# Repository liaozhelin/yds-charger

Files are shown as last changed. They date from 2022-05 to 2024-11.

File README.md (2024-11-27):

# 四路桌面智能充电站

> 这是一个实用型智能多路桌面充电器项目
>
> 视频介绍：[【开源】如何自制一个全能桌面充电站？](https://www.bilibili.com/video/BV1X94y1U7av/)
>
> 如果觉得视频还可以的话，留下一键三连哦 ( ˊ•̥▵•)੭₎₎
>
> 本项目欢迎复刻，禁止商用！！
>
> 整体成本（纯硬件）在50元左右，目前没有贵的离谱芯片，选用的芯片基本都是国产使用量较高的
>
> 有任何问题请在`issues`中提交哈，包括软件功能建议，其他平台的消息不一定看得到👀
>
> * 最近在咸鱼上能看到很多本项目的166W充电器的套件以及成品。在此声明这些均非本人上架，本人所有资料无偿开源，未从其中收取任何利益！本项目欢迎大家复刻改进、在合适的价格下出售有限数量的成品/套件（时间精力也是成本）方便新人，但不是商业化批量生产，高价出售并以此赚钱。有大佬在开源代码的基础上改进，并无偿开放了固件，在此表示感谢。请大家共同维护开源环境，国内开源环境已经很难了，尊重技术和开发者，开源才能走的更远！ 
>
> * 由于本人精力有限，未能继续维护该项目固件，在此和大家说一声抱歉~，但是还是有大佬们继续帮忙维护该项目固件，大家可以关注下他们的仓库，谢谢~~
>
>   [Zyilin98仓库]: https://github.com/Zyilin98/yds_charger?tab=readme-ov-file	""Zyilin98仓库""

5E3306F0C8ED8A1241D5FD975B7F77DC

**仓库目录说明**

1. `Hardware`：【上层板/下层板/前面板/后面板 】gerber文件/原理图源文件/原理图PDF文件/坐标文件/BOM文件
2. `Firmware`：【 ESP32C3FN4 的固件以及工具 】固件/驱动/下载烧录软件
3. `Software`： 【 软件工程源码 】esp-idf-4.4 版本开发环境
4. `Structure`： 【 整机结构文件 】包含电路板及外壳装配文件，软件版本Soliworks2022
5. `Documents`： 【 项目所用到的文档手册等 】部分手册，有些手册是厂家不让流传的没有上传

**资料说明 （更新日期22-5-30）**

- 已添加gerber文件，包含上层版，下层板，前面板，后面板，可直接打样（上层板若审核不通过备注断板不补即可）
- 已添加原理图源文件
- 已添加 README 文件 
- 已添加烧录软件,bootloader固件以及app固件
- 已添加结构设计文件夹
- 已添加手册文件夹
- 已添加 esp32c3 usb cdc/jtag驱动文件
- 已添加源码工程文件夹，希望大佬们可以帮忙改进，代码里有什么错误以及疑问都可以提交issue交流，当然能帮我完善功能就更好了😊
- 已提交新版上层板 (Gerber_topBoard-Fix.zip) ，修改掉不好生产的边框处后两层板实在没办法走通，改成四层板了，打样一样免费，就是颜色可能也得绿色了，可以先试试原版两层板，有概率通过，不通过再换成新版上层板。👀
- 已添加上下层板的动态BOM表，说明文件，可以方便焊接选料，若打样嘉立创不通过可以考虑捷配，新用户也可以免费打板审核也比较松。
- 已添加器件采购指南，只做样例，若链接失效自行找类似器件替换。
- 已添加不同丝印版本的文件，在每个板子文件夹中的others文件夹中，每一块板子都提供了3种不同的丝印版本，降低打样时候判定拆单的概率（实在不行就换其他打板公司或者换不同时间打样，基本上只要是机审就可以通过）
- 已经修改20V空载输入发热问题，更换3904的两个上拉电阻即可。

## 一、项目介绍：

### 1.1 硬件选型：

> 本项目的硬件购买都来自于淘宝，虽然有可能有假货，但是我没有翻车，大家可以酌情选择。

- 项目采用乐鑫**ESP32C3FN4**芯片作为控制MCU，具备Wifi和Bluetooth，价格便宜功能强大，可供二次开发增加许多其他功能(内置4M的FLASH)。
- C口功率级采用了智融**SW3526**的功率芯片（目前价格4.5元一片😍），该芯片支持多种快充协议，芯片内部集成功率管，减少PCB面积，最大功率为单通道65W，本项目中设计了两组通道。
- A口功率级采用了英集芯的**IP6525T**，价格低廉（目前价格1元一片😍），最大功率为单通道18W，本项目中设计了两路, 设计在机身后部, 主要是给桌面上的固定设备供电, 比如台灯, 小服务器等, 可通过MOS管远程控制开关
- 交互界面显示屏采用了**0.96**寸OLED屏（尺寸刚好,至于烧屏问题后面会通过屏保解决）。
- 输入部分设计了保护电路，具备防反接（方便车充应用）功能，反接系统不会工作。具备过流保护电路（10A），过流会熔断保险丝。具备防打火缓启动电路，可以防止上电火花。
- 板载四路RGB指示灯以及面板，可以实现当前系统状态的快速指示。
- 加速度传感器为**LIS3DH**，可以实现震动控制或者体感操作等功能。



### 1.2 项目参数

输入电压：10V-32V直流 (推荐使用换下来的笔记本充电器,咸鱼便宜量大,当然更推荐24V5A台达电源,可以最大程度发挥功率)

输入功率：＞80W （满载144W，但是一般不会全部满载）

快充参数如下：

- C口输出协议：PPS/PD3.0/PD2.0/QC4+/QC4/QC3.0/QC2.0/AFC/FCP/SCP/PE2.0/PE1.1/SFCP/BC2.1/苹果/三星
- C口输出电压：0.3-22V
- C口输出电流：0-3.3A
- A口输出协议：DCP/QC2.0/QC3.0/FCP/AFC
- A口输出电压：0.3-12V
- A口输出电流：0-3A

PCB参数：47*80(mm) 厚度1.6mm 四层板

整体尺寸（含外壳）：50X*20X*80(mm)

## 二、制作教程

### 2.1 制作注意事项

> 本产品焊接完成，测试无短路虚焊后，可通过下载口USB连接电脑，烧写程序后即可使用（ESP32C3自带内部USB和JTAG,十分方便）,如果不识别可能需要自行下载C3驱动安装即可

- 装机时请注意功率级部分的散热，推荐在功率级部分背面垫导热片增强散热能力。
- 焊接推荐采用钢网焊接，本项目中器件均为单面布置，可以快速实现低成本回流焊。
- 初次上电时，推荐使用5V电源，测量RY8411输出正常3.3V后才可以升高电压进行后面的测试。
- C1口为板载，C2口通过排针在上层板中引出。

上层板和下层板装配采用常规排针排母，但是排针需要**特殊处理**下，去掉塑料部分直接焊接，不然槽间高度不够：

| 第一步 | 第二步 | 第三步 | 第四步 | 第五步 |
| --- | --- | --- | --- | --- |
|  |  |  |  |  |
| 将排针插进上层板，顶在桌面上，往下按 | 取出后可以得到如上排针，按照这个样式制作三组 | 用水口钳去掉塑料部分，得到针脚 | 将排针插进下层板焊接好的排母中 | 将上层板子和下层板紧贴，排针插进洞中，然后焊接，这个距离刚刚好是两槽间距离 |

上层板的上面焊接完后，可以在上层铝壳对应位置贴上黑胶布绝缘（不贴也可以，实际上还有一定距离，保险起见）

### 2.2 固件烧录教程

> 通过Fireware/tools文件夹中的 flash_download_tool_3.9.2 工具下载
>
> 本项目暂时不提供PCB源文件，源码已经全部开源，有需要二次开发的朋友可以自行修改

	本项目不需要烧录器/下载器，只需要你有一个USB线，但是需要自己焊接一个降压电路将USB口的5V转到3.3V（或者不从排针3.3V处供电，直接通过DC口供电）,**一定不要把5V接到板子上的3.3V处，必烧ESP32**，我是使用了一个洞洞板+AMS1117焊接的简单下载器：

| 烧录器 | 烧录器连接板子 |
| :---: | :---: |
|  |  |

1. 合并固件位置在 `Fireware/bin/target.bin` ，独立固件位置在 `Software/yds_charger` 中，推荐不打算自己后续开发的使用合并bin下载方式。

2.  软件打开后将设备连接到电脑，如图片`图1`设置好下载模式后，点击OK。

3. 【合并bin下载方式】按照下面的图片`图2 `设置好软件，点击下载应该就可以下载固件了，一共需要烧录一个固件即可，地址设置0

4. 【独立bin下载方式】按照下面的图片`图3 `设置好软件，点击下载应该就可以下载固件了,一共需要烧录四个固件，注意地址设置

   > 如果出现连接错误可以将上板后面的拨动开关向左(从前面看，也就是上面板有时间编号的那一边)拨住**不松**，然后再上电，就会进Boot模式）烧录完成，断电后重新上电，应该就可以正常使用了。

	烧录完成后，重新上电复位，就可以使用了。

| 图1 | 图2 | 图3 |
| :---: | :---: | :---: |
|  |  |  |

	OTA采用了 APP+OTA1+OTA2 的乒乓式更新分区（这样就算更新到一半断电断网也不会变砖），首次烧录完后续盖上盖子后，后续就可以使用无线更新了。

## 三、IDF开发

### 3.1 开发环境搭建

	IDF开发环境我是在 Windows 系统中使用 `VScode+idf拓展插件` 在Python虚拟环境中实现开发的，实际上也可以在Linux中直接搭建环境开发，或者使用`WSL+VScode远程插件` 也是可以的，可以根据自己的需要进行选择，详细的搭建步骤可以见[官网搭建流程](https://docs.espressif.com/projects/esp-idf/zh_CN/release-v4.1/get-started/index.html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)：

	下面以我的`VScode+idf拓展插件` 搭建环境为例：

1. 安装Vscode，这个直接下载安装即可，然后在左侧的应用市场中，搜索关键词 Espressif IDF，安装：

   

2. 插件安装完成后，按`F1`,在命令中找到`Configure ESP-IDF extension`选项，点击：

   

3. 选择ADVANCED模式，可以详细配置一些选项：

   

4. 依次设置软件源，IDF版本，IDF路径，IDF工具路径。软件源如果你科学就可以直接选择Github，没有科学可以选择Espressif的国内源，IDF版本这里选择`release/4.4`,其他两个可以根据自己进行设置（路径中不要出现中文或者空格），推荐使用默认路径，然后点击 `Install` 进行安装：

   

5. 等待ESP-IDF下载安装完成，IDF整体体积不小，具体看网速：

   

6. 接下来安装ESP-IDF工具，其中包含虚拟环境以及虚拟环境中用到的一些工具链，选择 `Download ESP-IDF Tools`选项，点击 `Download Tools`：

   

7. 等待工具安装完成：

   

8. 若出现如下页面，则安装完成，如果上述中有步骤报错，一般就是网络问题：

   

### 3.2导入工程开发

	本项目的工程在 `Software/yds_charger` 下，将项目克隆到本地，主要修改项目中的.vscode文件夹，这个文件夹中的文件控制着IDF插件的功能以及Vscode本身的代码高亮提示跳转等。

	先验证安装环境是否可以正常使用，按`F1`,在命令中找到`New Project`,点击：



	根据自己喜好修改工程名，路径，板子，串口（没接上电脑就不用选），最后一个选项可以不管，点击 `Chose Template`：



	下拉框中选择 `ESP-IDF` ,这里可以选择一个最简单的项目测试下，`sample_project`，选择好后点击蓝色按钮生成工程，并信任文件夹中的作者并启用所有功能:



	点击工程下面框中的编译按钮，等待编译完成，若能成功生成bin文件则环境搭建成功（编译如果很慢的话，关闭Windows的病毒防护，可以极大提高编译速度）：





	验证完编译环境后，可以将示例工程中.vscode中文件复制到克隆下的工程中，或者使用 `F1` 中的添加.vscode文件命令也可以，应该包含下面四个文件：



	后面就可以愉快地开发了，烧录下载也一样是用下面的按钮，这里就不赘述了：



**功能开发（更新日期22-5-27）：**

✅ 已经开发完成   🚩正在开发中   ❌还未开发或放弃开发

| 设计功能 | 状态 | 说明 |
| :---: | :--: | :---: |
| 远程网络升级（OTA） |  ✅ | 带固件版本号校验 |
| WIFI配网 |  ✅ | 通过ESPTouch软件配网 |
| 主界面显示 |  ✅ | 待机休眠屏保待完善 |
| 快充协议解析 |  ✅ | 已实现 |
| RGB指示灯 |  ✅ | 已实现，控制逻辑待完善 |
| 各口电压电流监测 |  ✅ | 已实现 |
| 过流反接保护 |  ✅ | 以实现，已校验 |
| 远程控制充电器四口开关 |  🚩 | 硬件已验证，还未写逻辑 |
| 加速度计(重力感应) |  🚩 | 程序已驱动，还未写功能 |
| C口功率限制 |  🚩 | 程序已实现，界面还未增加 |
| OTA自动检测版本升级 |  🚩 | 版本验证已完成，json解析还在修改 |
| 电脑CPU占用，内存占用显示  |  ❌ | 还未开发 |
| 天气显示 |  ❌ | 还未开发 |
| 粉丝数显示 |  ❌ | 还未开发 |
| 重力旋转屏幕 |  ❌ | 还未开发 |
| 蓝牙广播检测手环自动开关机 |  ❌ | 还未开发 |
| | | |
| | | |
| | | |

> 本项目禁止商用，仅供同好们复刻使用，在制作项目时候，请确保硬件无故障再连接设备使用（我已经使用了两个月，目前没有出过问题，手头设备不是很多，所以测试可能不是很完善，不能保证系统不存在隐藏的问题。希望大家能发现问题一起改进），对于造成高价值设备损坏以及其他连带损失的的，本人不承担任何责任哈。
>
> 海拔高度：＜ 2000米
>
> 环境湿度：≤ 75% RH
>
> 工作环境：0℃ - 50摄氏度

大佬们复刻成功的成品 (每一张表格是同一作者的成品)：

`2022-6-13`

|  |  |  |  |
| --- | --- | --- | --- |

`2022-6-14`

|  |  |  |  |
| --- | --- | --- | --- |

`2022-6-16`

|  |  |  |  |
| --- | --- | --- | --- |

`2022-6-18`

|  |  |  |  |
| --- | --- | --- | --- |

......

🙌有啥问题随时提issues，已经有人复刻成功了

......

最后纪念一下开发过程中的炮灰小弟们，第一代和第三代还有打孔歪了的==（总共迭代了5版本，其中有2代搬板拆了）：

|  |  |
| --- | --- |

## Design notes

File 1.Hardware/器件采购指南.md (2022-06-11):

# 四路充电器-采购指南

更新日期：5月30日

> 所有的器件，推荐有闲钱的可以上立创商城之类的购买，保证正品，如果想要折腾的可以在淘宝购买即可（我的器件都是淘宝买的）

以下的指南主要是一些比较难采购到的器件，很常见的电阻电容之类的就不说了：

- 主芯片是 ESP32C3FN4, 要买有内置FLASH版本的

- 外壳：https://item.taobao.com/item.htm?id=596749209315

- 下层板：

| 位号 | 关键字 | 链接 | 图片 |
| :---: | :---: | :---: | :---: |
| L1,L2 | CEP1411NP | https://item.taobao.com/item.htm?id=39992169602  |  |
| L5,L6 | RH屏蔽电感 | https://item.taobao.com/item.htm?id=623801536508 |  |
| C1,C44 | 直插固态电容 | https://item.taobao.com/item.htm?id=660777715260 |  |
| C59,C60,C4,C65,C61 | 高频低阻直插铝电解电容 | https://item.taobao.com/item.htm?id=618159081612 |  |
| C21,C50 | 高频低阻长寿命直插电解电容 | https://item.taobao.com/item.htm?id=617486024887 |  |
| U1,U2 | SW3526 | https://item.taobao.com/item.htm?id=645362899959 |  |
| | | | |

- 上层板：

| 位号 | 关键字 | 链接 | 图片 |
| ---- | --- | --- | --- |
| SW2  | 转换开关 三向开关 | https://item.taobao.com/item.htm?id=614104886426  |  |
| USB1 | TYPE-C 母座 USB 3.1 | https://detail.tmall.com/item.htm?id=668795388622 |  |
| | | | |

- 上下板连接器：使用普通的2.54排针，下层焊接排母，上层排针**去掉塑料**部分，直接焊接

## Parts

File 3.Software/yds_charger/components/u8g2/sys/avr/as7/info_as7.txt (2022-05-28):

001: plain as7
002: create a new gcc c executable project, enter a useful name and solution name
003: select your target device
004: as7 will generate a main.c file. Replace the content of the generated main.c with 
the content of https://github.com/olikraus/u8g2/blob/master/sys/avr/atmega328/main.c
005: open the project Properties (Alt+F7)
006: Add Existing item...
007: Mark and add all files of the u8g2/csrc directory, press "add"
008: Select the project, locate Toolchain tab, select "All Configurations", select AVR/GNU C Compiler/Directories and press the green plus icon
Add ".." as relative include path
009: Select the project, locate Toolchain tab, select "All Configurations", select AVR/GNU C Compiler/Symbols and press the green plus icon
Add the target frequency of your controller (here: "F_CPU=8000000")
010: Press F7 (Build->Build Solution)
011: On my own Windows 10 environment, it was required to install a different usb driver for the AVRISP mkII
012: Open the Device Programming dialog (Tools menu)
013: 
	Select your ISP tool in under "Tool". Select the correct target device and interface. Press "Apply" button.
	Read the device signature from your target controller by pressing the "Read" button.
	Goto "Production file" tab and select the generated .elf file as a "production file"
014: Check "Flash" and press the "Program" button.

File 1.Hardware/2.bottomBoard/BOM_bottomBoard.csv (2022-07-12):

ID | Name | Designator | Footprint
1 | RY8411 | BS | SOT-23-6_L2.9-W1.6-P0.95-LS2.8-BL
2 | 220uF/35V | C1,C4,C44,C61,C65 | CAP-TH_BD8.0-P3.50-D0.6-FD
3 | 105 | C2,C3,C6,C8,C9 | C0603
4 | 107 | C5 | CASE-B_3528
5 | 104 | C7,C14,C16,C17,C18,C54 | C0603
6 | 225 | C10 | C0603
7 | 475 | C11,C12 | C0603
8 | 106 | C13,C15 | C0603
9 | 10p | C19,C20 | C0603
10 | 470uF/16V 8*9 | C21,C50 | CAP-TH_BD8.0-P3.50-D0.6-FD
11 | 0.1u | C22,C29,C32,C35,C38,C43,C46,C49,C51,C55,C56,C57 | C0603
12 | 10u/35V | C23,C33 | C0805
13 | 0.1u/50v | C24,C30,C37,C47,C48 | C0603
14 | 22u/35V | C25,C42 | C0805
15 | 330p | C26,C27,C40,C41 | C0603
16 | 1n | C28,C39,C45,C52 | C0603
17 | 1u | C31,C36 | C0603
18 | 10u/25V | C34,C62 | C0805
19 | NC | C53,C63 | C0603
20 | 10u/35V | C58 | C0603
21 | 100uF/35V 8*9 | C59,C60 | CAP-TH_BD8.0-P3.50-D0.6-FD
22 | 10u | C64 | C0805
23 | BZT52C3V3_C216707 | D2 | SOD-123_L2.7-W1.6-LS3.7-RD
24 | DC-044A-20A | DC2 | DC-IN-TH_DC-044A-20A
25 | Header-4P | H1,H7 | HEADER-4
26 | HDR-F-2.54_1x3 | H2,H3,H4,H5,H6 | HDR-F-2.54_1X3
27 | 22uH | L1,L2 | IND-SMD_3P-L14.5-W14.5
28 | 2nH | L3 | L0603
29 | AN9520-245 | L4 | ANT-SMD_L9.5-W2.1
30 | 22uH | L5,L6 | IND-SMD_L12.0-W12.0_CDRH127NP
31 | 4.7uH | L7 | IND-SMD_L4.0-W4.0_CD43L-10UH
32 | WS2812B-2020 | LED1,LED2 | LED-SMD_4P-L2.0-W2.0-TL_WS2812B-2020
33 | VG-2864KSWEG01 | OLED1 | OLED_0.96-30P-P0.70-12864
34 | TPCA8016-H | Q1 | POWERVDFN-8_L6.2-W5.2-P1.27-LS6.0-BL
35 | SI2309 | Q2,Q3 | TO-236-3_L2.9-W1.3-P1.90-LS2.4-BR
36 | LMBT3904DW1T1G | Q4 | SOT-363_L2.0-W1.3-P0.65-LS2.1-TL
37 | 10K | R1,R4,R6,R21,R24,R29,R30 | R0603
38 | 2R | R2,R13,R15,R16 | R0603
39 | 10mR | R3,R14 | R1206
40 | 33K | R5,R12 | R0603
41 | 4.7K | R7,R8,R11 | R0603
42 | N/A | R9 | R0603
43 | 910K | R10 | R0603
44 | 62K | R17 | R0603
45 | 20K | R18 | R0603
46 | NC | R19 | R0603
47 | 51K | R20 | R0603
48 | 6.2K | R22,R25 | R0603
49 | 1k | R23,R26 | R0603
50 | 1K | R27,R28 | R0603
51 | SW3526 | U1,U2 | QFN-24_L4.0-W4.0-P0.50-TL-EP2.5
52 | IP6525T | U3,U8 | ESOP-8_L4.9-W3.9-P1.27-LS6.0-BL-EP
53 | ESP32C3 | U4 | QFN-32_L5.0-W5.0-P0.50-BL-EP3.7
54 | 1808 Base | U5 | FUSE-SMD_L9.7-W5.0
55 | 1N4148FL | U6 | SOD-123FL_L2.8-W1.7-LS3.6-RD
56 | LIS3DHTR_C15134 | U9 | LGA-16_L3.0-W3.0-P0.50-TL
57 | TYPE-C16PIN | USB1 | USB-C-SMD_TYPE-C16PIN
58 | USB-240-BRW | USB3,USB8 | USB-A-TH_USB-240-BRW
59 | 40MHz | X1 | CRYSTAL-SMD_4P-L3.2-W2.5-BL

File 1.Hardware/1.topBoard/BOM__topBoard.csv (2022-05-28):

ID | Name | Designator | Footprint | Quantity
1 | 104 | C1,C2,C17 | C0603 | 3
2 | HDR-F-2.54_1x3 | H2,H3,H4,H5,H6 | HDR-F-2.54_1X3 | 5
3 | WS2812B-2020 | LED1,LED2 | LED-SMD_4P-L2.0-W2.0-TL_WS2812B-2020 | 2
4 | 10K | R1,R2,R6 | R0603 | 3
5 | TM-2022-3 | SW2 | SW-SMD_TM-2022-3 | 1
6 | TYPEC-302-BRP16SC08 | USB1 | USB-C-SMD_TYPEC-302-BRP16SC08 | 1

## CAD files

3.Software/yds_charger/components/u8g2/sys/arduino/u8g2_full_buffer/SwitchBox/board.dxf
60
40
52
8
24
80
30
32
25
100
190
4
12
6
14

3.Software/yds_charger/components/u8g2/sys/arm/stm32l031x6/clock.dxf
65
32
28
16
Draufsicht
Vorderansicht
von unten
von rechts
von links
14
6
45
60
30
20
8
35
75
55
10
12

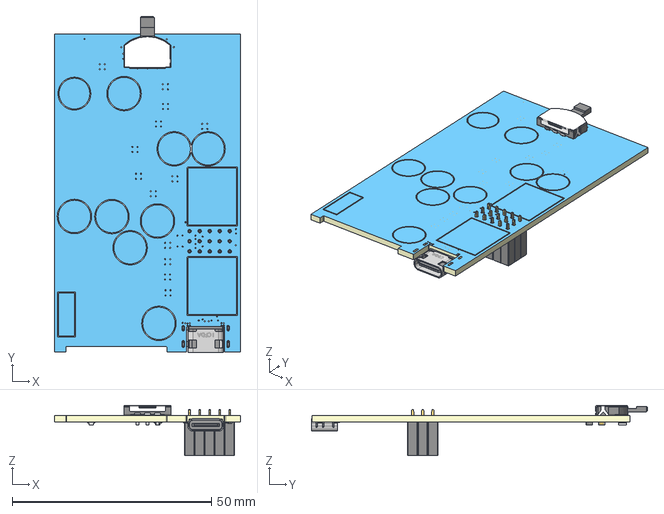
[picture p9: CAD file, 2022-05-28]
4.Structure/bottomBoard/3D_2_PCB_Daughter-Board_2022-04-09_2022-04-09.step
46.7 x 84.2 x 12.6 mm

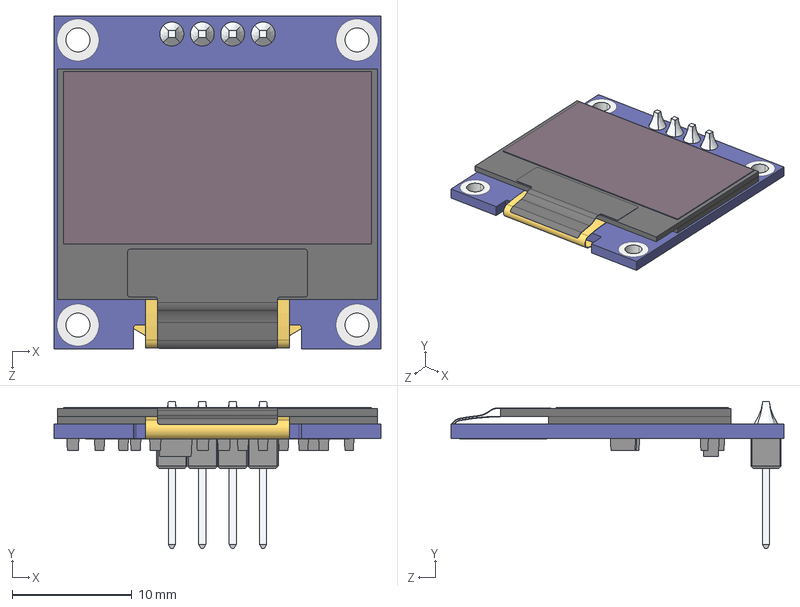
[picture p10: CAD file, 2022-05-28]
4.Structure/otherModule/OLED/OLED TFT 0.96 inch 64x128 monochrome.STEP
27.3 x 12.3 x 27.8 mm

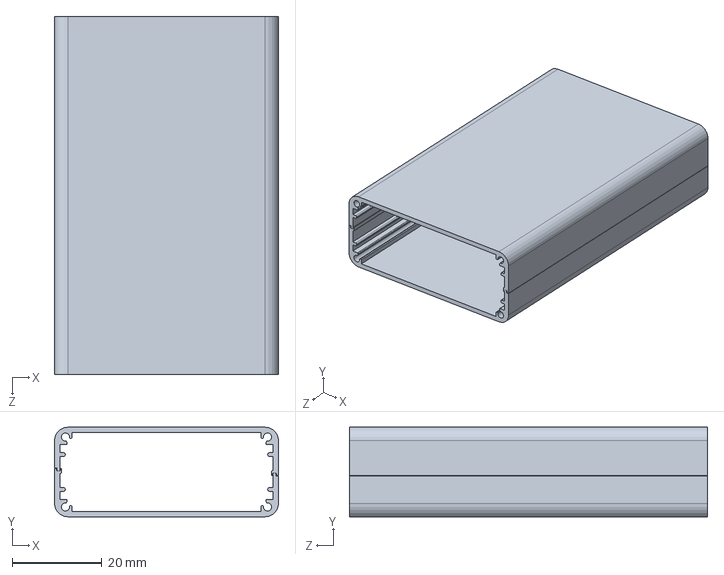
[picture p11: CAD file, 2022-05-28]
4.Structure/铝壳2050.SLDPRT
50.0 x 20.0 x 80.0 mm

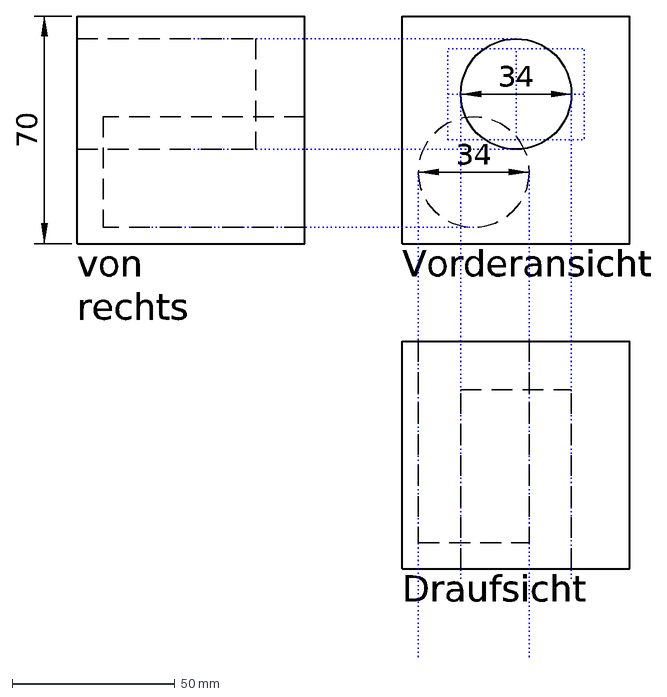
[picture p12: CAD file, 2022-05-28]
3.Software/yds_charger/components/u8g2/sys/arm/stm32l031x6/clock_cube.dxf
Draufsicht
Vorderansicht
von rechts
70
34

3.Software/yds_charger/components/u8g2/sys/arm/stm32l031x6/clock_2.dxf
65
Draufsicht
Vorderansicht
von unten
von rechts
von links
14
30
32
35
75
55
10
12
16
11
22
34
28
29
18
93
19
43
15
68
60
57
150
Holzbohrer: 2.5, 8, 10, 12, 16, 32mm
8
7
6
2.5mm

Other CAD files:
4.Structure/otherModule/OLED/OLED TFT 0.96 inch 64x128 monochrome.SLDPRT
4.Structure/otherModule/OLED/OLED TFT 0.96 inch 64x128 monochrome.x_t

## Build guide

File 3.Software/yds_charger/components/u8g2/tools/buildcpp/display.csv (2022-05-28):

# 1. device name
# 2. pinset
# 3. constructor name w/o prefix
u8x8_d_ssd1306_128x64_noname | 4WSWSPI | SSD1306_128X64_4W_SW_SPI
u8x8_d_ssd1306_128x64_noname | 4WHWSPI | SSD1306_128X64_4W_HW_SPI
u8x8_d_ssd1306_128x64_noname | 3WSWSPI | SSD1306_128X64_3W_SW_SPI
u8x8_d_ssd1306_128x64_noname | SSDSWI2C | SSD1306_128X64_SW_I2C
u8x8_d_ssd1306_128x64_noname | 6800 | SSD1306_128X64_6800
u8x8_d_ssd1306_128x64_noname | 8080 | SSD1306_128X64_8080

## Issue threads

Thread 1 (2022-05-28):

制板的时候的问题

Zyilin98, 2022-05-28:
找jlc制顶板的时候 被嘉立创告知无法制版 需要修改图纸
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
这个是直接告啥嘉立创直接做 还是需要硬件部分迭代

Zyilin98, 2022-05-28:
顺便老哥 你传个LICENSE文件到GitHub上 保证一下开源协议 省的被人直接扒走

liaozhelin, 2022-05-28:
你好，这个直接标注强制生产即可（断板不补就行），后续我会修改一版，去掉这些细连接处，尽可能降低生产的难度

liaozhelin, 2022-05-28:
> 顺便老哥 你传个LICENSE文件到GitHub上 保证一下开源协议 省的被人直接扒走

好的谢谢提醒，我资料还没上传完，等弄好把license也整上

Zyilin98, 2022-05-28:
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
ma'le麻了 给他说了直接做就行 断了就断了 结果还不行 我好佩服嘉立创这么敬业

liaozhelin, 2022-05-28:
> 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
> ma'le麻了 给他说了直接做就行 断了就断了 结果还不行 我好佩服嘉立创这么敬业

好家伙，我之前打样了不下5次都没有问题，现在居然变严格了，那我后面改一版本去掉这些细的边框看看，就是有可能变四层板，有些线走不出来了hh，你可以换个号试试看，只要不触发人工审核一般都可以通过

Zyilin98, 2022-05-28:
我现在下单全都是 人工审核 不管换哪个号 属实是麻中麻

liaozhelin, 2022-05-28:
>

看来审核规则改了hhh，那我后面改个板子，这个是上层板就是一些转接的功能，你可以先做下层板，备料还是需要些时间的hh

Zyilin98, 2022-05-28:
好的 感谢 先把下层做了吧 上层等迭代吧

liaozhelin, 2022-05-29:
已经提交上层迭代版本

Zyilin98, 2022-05-30:
麻了 老哥你能把 pcb文件私法我一份 我改一下么 今天我又被jlc认为是拼单了 让他生产 就叫我补全款 换个号也这样 麻了

liaozhelin, 2022-05-30:
嘉立创打样成功的人不少欸，现在可能打样的人太多了，可以试一下华秋和捷配，这两个也是免费打样，华秋是四层板刚好可以，你邮箱也发我个哈

Zyilin98, 2022-05-30:
> 嘉立创打样成功的人不少欸，现在可能打样的人太多了，可以试一下华秋和捷配，这两个也是免费打样，华秋是四层板刚好可以，你邮箱也发我个哈，实在不行我再改下发你 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

Zyilin98@gmail.com

liaozhelin, 2022-05-30:
资料已发

Zyilin98, 2022-06-08:
老哥，就是关于esp的接口那里 能不能做个直插式的焊盘 这样也方便焊排针？

QGB, 2022-10-30:
0 C:/test/jlc-eda/hqdfm_hqdl_wz.zip       <76.868 MiB> c39a170fac7e5c70a4e15cb5e3b8f759 7de4cede0c139a28a684beb1d50a0c6915c6ac9bbfe5cffb7e195cd4865488d1
 {'C:/test/jlc-eda/hqdfm_hqdl_wz.zip': [<76.868 MiB>, <2022-10-30__13.30.29__.970>, <2022-10-30__13.30.29__.970>, <2022-10-30__13.29.59__.064>, <0o100666>]}

Closed 2022-05-30.

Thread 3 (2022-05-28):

问一下，有可能公开esp固件的代码么

yelvlab, 2022-05-28:
为了学习思路，实话您这个项目看成品做的效果不错，但是开源之名多多少少差点意思，搭配硬创社，没话说，有可能的话留个话，没可能就关了吧

liaozhelin, 2022-05-28:
说了开源那肯定得开，正在修改依赖的子模块，预计晚上可以上线第一个版本。至于硬创社和我这个项目关系不大，因为这里的资料比硬创社更全

liaozhelin, 2022-05-28:
ho

> 为了学习思路，实话您这个项目看成品做的效果不错，但是开源之名多多少少差点意思，搭配硬创社，没话说，有可能的话留个话，没可能就关了吧

说了开源，那肯定要开的，我还希望有大佬能帮我提交PR完善后续固件，审查我的代码呢。已经整理的差不多了，预计晚上可以上传第一个版本，工作区有点乱正在整理中。至于硬创社，并没有资料是在硬创社独有的，只是给没办法访问github的朋友们一个更方便下载资料的地方（最近gitee都知道，提交每次审核那得烦死），最后希望开源后能够有大佬们一起完善这个项目，我主要用业余时间搞的，很多细节可能都不是很到位，只要不被商业化拿来盈利就可以了😼😼

liaozhelin, 2022-05-28:
已提交源码工程

Closed 2022-05-28.

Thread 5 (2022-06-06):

器件选型问题

stig3, 2022-06-06:
1. R5/R12 两个电阻，规格书要求接33K 1%的实现 65W MAX 输出，原理图上是34K，这个有什么考虑吗？34K是非标电阻，也买不到。
2. R17/R18是开关电源的FB，31K也是非标电阻，建议使用62K/20K这样的搭配
3. C42/C25这两个22uF的电容是跨接在USB BUS上的，这两个电容耐压有要求，不能小于20V，建议标注出来，不然会炸的。
4. C62/C34这两个10uF的电容也要16V电压档的
5. C58这个0603的电容也要耐压35V的

liaozhelin, 2022-06-06:
1. R15/R12这两个电阻，可以使用33K的，这个实际上应该不焊接都可以，作用是在没有I2C配置sw3526时候，通过电阻配置功率

liaozhelin, 2022-06-06:
已经更新文件

Closed 2022-06-06.

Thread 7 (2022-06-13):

如果使用jlink cmsis-dap 应该怎么接线 我手里暂时还没有usb公头

Zyilin98, 2022-06-13:
老哥 如果使用jlink cmsis-dap 应该怎么接线 我手里暂时还没有usb公头 再为了这个去买 感觉有点不值

liaozhelin, 2022-06-13:
> 老哥 如果使用jlink cmsis-dap 应该怎么接线 我手里暂时还没有usb公头 再为了这个去买 感觉有点不值

这个硬件上无法使用JLINK下载，JLINK的JTAG占用管脚过多，C3引脚都用完了没有引出，USB公头就几分钱一个，所以选用的片内USB下载，这个USB也内建了JTAG调试器的

Zyilin98, 2022-06-13:
串口下载有办法么 没有的话我还是去拆条usb线吧

liaozhelin, 2022-06-13:
> 串口下载有办法么 没有的话我还是去拆条usb线吧
可以串口下载，但是我没有验证，板子背面预留了串口触点，应该是一样的，就是可能需要手动进入boot模式

Closed 2022-06-13.

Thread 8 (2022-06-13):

固件下载进去没显示，led也没亮

X131402, 2022-06-13:
固件是按图片设置下载的，但是我做了三个都没显示，输出全部都正常，不知道是哪里的问题？🥹

liaozhelin, 2022-06-13:
> 固件是按图片设置下载的，但是我做了三个都没显示，输出全部都正常，不知道是哪里的问题？🥹

你好，我复查后发现是第一次提交的教程，有个bin文件的地址有错误，我现在提交了合并版本的固件，已经在我的电脑上验证了教程，可以通过烧录合并固件，直接烧录一个即可，详细说明可以见更新后的Readme。目前固件功能是第一屏还有设置界面，第二界面的天气显示还在开发中，第三界面预留，第四界面是设置界面，可以通过后面的拨动按键切换。如果制作成功也可以在issue中反馈下，给其他人参考😘

X131402, 2022-06-13:
你好，屏幕有显示了，但是卡在wifi网络初始化就不动了，这个是哪里的问题呀。下载的是整合固件

liaozhelin, 2022-06-13:
> 你好，屏幕有显示了，但是卡在wifi网络初始化就不动了，这个是哪里的问题呀。下载的是整合固件
wifi初始化后是提示OK还是ER?

X131402, 2022-06-13:
就是屏幕显示到最后一条wifi网络初始化... ，就不动了，进不了主页面，然后也没显示OK和ER，就卡在那里

liaozhelin, 2022-06-13:
> 好的，谢谢了

你好，已经提交修复版本的固件，你烧录后看看，应该初次是会提示NO，然后后面开关向右拨动四次进入设置界面，选择 **无线配置-配网** 然后再用手机的esptouch软件给设备配网，配网成功后手机会提示设备也会自动退出配网状态，SSID和密码也会存储在设备中，重新上电后应该就会提示OK了

X131402, 2022-06-13:
已经可以了，联网也正常，谢谢!

X131402, 2022-06-13:
感谢！！

Closed 2022-06-13.

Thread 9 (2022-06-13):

识别到设备但无法烧录

blacksr, 2022-06-13:
dalao你好
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
！
使用外部的电源给的3.3，GND和USB的GND共在一起了，识别出设备后烧录时报了以上的错误，波特率1152000和115200都试了都不行，请问是什么原因可能导致的呢
以下是我遇到的一些问题
1、我将元件焊接完成后DC给了5V测量了RY8411输出是3.6V左右，但DC给24V后RY8411输出就是3.3V了，这部分会影响吗
2、电脑识别时会识别出来然后断开再识别再断开，反复不断，此时3.3V供电电流大约是16mA左右，将拨动开关往左拨进入bootmode后就能正常识别了，此时电流大约是20mA左右，请问这样的现象是正常的吗

blacksr, 2022-06-13:
好的好的谢谢解答！
1、电压正常的话我就放心了
2、如果下载模式指的是拉住拨动开关后上电的话，那么我的操作应该是没有问题的，进入了下载模式后就不会断连了，不进入就会，我还没有尝试烧录完成后还会不会断连【因为烧录不进去:(】芯片我刚刚确认了一下，应该是买错了，没有带尾缀FN4
这个是我买的物料链接，看起来是买错了的
https://item.szlcsc.com/3013220.html

liaozhelin, 2022-06-13:
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

是的，ESP32C3物料购买错误这个是我前期的BOM中的疏忽导致的，lceda最开始导出BOM时候去掉了备注栏，没有注明flash版本，前几天已经修订了BOM中器件型号和更新了说明文件，价格上的话应该贵个2元左右

blacksr, 2022-06-13:
另外我使用了PD测试仪测了一下，虽然没有烧录，USBA口其实已经开始工作了，能够测的出来协议了，不过USBC就还不行:)

liaozhelin, 2022-06-13:
> 另外我使用了PD测试仪测了一下，虽然没有烧录，USBA口其实已经开始工作了，能够测的出来协议了，不过USBC就还不行:)

USBC的sw3526应该是要等esp32烧完程序后，i2c配置使能后才可以工作，应该是没有问题

blacksr, 2022-06-16:
更换了32芯片之后就好了！感谢dalao分享的方案！

blacksr, 2022-06-16:
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

blacksr, 2022-06-16:
外壳打算3d打印一个看一下，满载跑一下老化看看温度，要是温度高搞个铝壳底板打印外壳

liaozhelin, 2022-06-16:
不推荐3D打印，散热挺差的，pla肯定会变形，铝壳也不贵，而且还有前后螺丝

blacksr, 2022-06-16:
不行就底板改用铝板加导热贴，3D打印只是外形而已，或者说先用3D打印机验证模型尺寸后面直接CNC一块板子出来，CNC可以薅公司的用一下，打印机我倒是自己有

liaozhelin, 2022-06-16:
原来是有cnc的dalao，那就更舒服了，可以说上下铣些散热沟槽，高功率下应该会更稳定

blacksr, 2022-06-16:
散热还是挺重要的，毕竟我给笔记本充电的话65W是得吃满的，主要是觉得那个通用外壳有点捞

Closed 2022-06-15.

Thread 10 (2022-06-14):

寄了 电脑认不到板子，串口也不认

Zyilin98, 2022-06-14:
反正是历尽千辛万苦终于做出来一个版本 然后 3.3Vdc-dc电路哪里也正常出了3.3V 但是led没一个亮的 双sw3526也没有输出 倒是A口哪里开始有输出了
接电脑 不管是usb直通 （3.3V已经提供了）还是用ch340通过串口连接 设备基本上就认不到 本来我以为是上层版没做的原因 做了顶层版 按着波动开关还是不认  我已经麻了 实在是不知道哪里的问题导致电脑不认esp32了 显示屏还没焊 怕万一esp32烧了 显示屏一块带走 损失更大

liaozhelin, 2022-06-14:
led在没有烧程序的时候亮是正常的，至于不认芯片，这个电脑是提示无法识别的设备，还是什么提示都没有？

Zyilin98, 2022-06-14:
> led在没有烧程序的时候不亮是正常的，至于不认芯片，这个电脑是提示无法识别的设备，还是什么提示都没有？ 主控芯片是否买的有内置flash版本的c3fn4？

电脑什么提示都没有 设备管理器连弹窗都没有 买的是ESP32-C3FH4

liaozhelin, 2022-06-14:
> > led在没有烧程序的时候不亮是正常的，至于不认芯片，这个电脑是提示无法识别的设备，还是什么提示都没有？ 主控芯片是否买的有内置flash版本的c3fn4？
>
> 电脑什么提示都没有 设备管理器连弹窗都没有 买的是ESP32-C3FH4

方便提交下你的焊接完的板子和连线照片嘛？

Zyilin98, 2022-06-14:
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

Zyilin98, 2022-06-14:
还没来得及洗板子.....

liaozhelin, 2022-06-14:
> 还没来得及洗板子.....

目前我所看到的器件应该都正常，可能还是要重点检查下USB DM DP这两个到芯片的焊接是否虚焊

Zyilin98, 2022-06-15:
去量了 出了一个0.15V 然后Q2 Q3这个Si2309 D极只有0.15V的电压 然后Q4 LMBT3904DW1T1G 除了从E_1 E_2这里有高电压 剩下的位置对地基本上没什么电压

Zyilin98, 2022-06-15:
再去看了一下 要么是esp32挂了 要么就是虚焊 因为3.3的电路都蛮好的  我感觉虚焊可能性不高 因为已经尝试过加焊了 拆下来的时候焊盘也没连锡

liaozhelin, 2022-06-15:
> 再去看了一下 要么是esp32挂了 要么就是虚焊 因为3.3的电路都蛮好的 我感觉虚焊可能性不高 因为已经尝试过加焊了 拆下来的时候焊盘也没连锡

是的，如果手头有空余芯片可以替换下看看

gzzz2008, 2022-07-05:
我也出现这种情况，链接电脑没有任何反应，最后怎么解决的呢？

Zyilin98, 2022-07-05:
> 我也出现这种情况，链接电脑没有任何反应，最后怎么解决的呢？

第一个检查3.3V供电有没有出 有了就检查C15的电压是不是3.3V 如果两个都是 还是不认 检查usb接口焊接 和接口定义是不是接错了
然后检查晶振是不是正常工作 是不是正常起振  如果还是不行 就直接换个esp32吧

gzzz2008, 2022-07-05:
没有示波器怎么检查晶振呢？

Zyilin98, 2022-07-06:
> 没有示波器怎么检查晶振呢？

第一个你的晶振得是无源晶振 第二个晶振有四个触点 看四个触点的定义是不是跟pcb上的一样(就是你有没有焊反了)
第三个就是检查有没有起振 这个是必须要示波器的
第第四 看看c15这个电容有没有对地3.3的电压 有才能算esp32可能正常工作 如果没有就esp32根本没有工作

Closed 2022-06-15.

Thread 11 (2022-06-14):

10pf的0603电容电压应该是多少v呢 我找了许多只有50v的

Tomoneplus, 2022-06-14:

liaozhelin, 2022-06-14:
是两个晶振的匹配电容吗，这个无所谓，买耐压最低的就行，有要求耐压的电容是电源主线上的电容

Tomoneplus, 2022-06-14:
还有0.1uf的也是只有50v

liaozhelin, 2022-06-14:
> 还有0.1uf的也是只有50v

0.1uf的电容一般买25V的就可以

Tomoneplus, 2022-06-14:
0.1uf 25v的可以发个连接吗 我找了好多都是50v的

liaozhelin, 2022-06-14:
> 0.1uf 25v的可以发个连接吗 我找了好多都是50v的

可以买50V的，没有问题

Tomoneplus, 2022-06-14:
找到了 1uf25v 105k

liaozhelin, 2022-06-14:
> 找到了 1uf25v 105k

嗯嗯，除了输入总线上的电容外其他电容无需太过在乎耐压值

Closed 2022-06-14.

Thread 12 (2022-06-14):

大佬你好

Sirius-Cooper, 2022-06-14:
大佬你好，我现在做好了，充电啥的功能也实现了，但是WIFI配网完成以后那个气象站不显示，请问这是正常的嘛，还有我想问一下有OTA升级时选中自动更新会是什么反应

liaozhelin, 2022-06-14:
是的，气象站的API还在开发中，因为目前用的个人天气API无法给多人使用，所以先屏蔽了，正在搞服务转发中。OTA升级中的自动更新还未写功能，后续实现的功能就是每天轮询，查询到新固件版本后自动更新。

Sirius-Cooper, 2022-06-14:
好的，感谢大佬

Closed 2022-06-14.

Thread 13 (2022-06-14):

原理图源文件如何打开

Gonglja, 2022-06-14:
哈喽，大佬好，想换点器件，将65w升级为100w，请问原理图源文件是哪个？那个json文件吗？
如方便，告知下软件

liaozhelin, 2022-06-14:
> 哈喽，大佬好，想换点器件，将65w升级为100w，请问原理图源文件是哪个？那个json文件吗？
>
> 如方便，告知下软件

使用lceda打开，换成100w的话可能得重新方案选型才行，这个体积可能不好塞的下

Gonglja, 2022-06-14:
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

好的，感谢，芯片目前考虑 3519、3518s，顺便换一下彩屏

Gonglja, 2022-06-17:
up您好
看了下里面没有pcb文件，方便发下嘛，需要改下设计
我的邮箱是 glj0艾特outlook.com

liaozhelin, 2022-06-17:
> up您好 看了下里面没有pcb文件，方便发下嘛，需要改下设计 我的邮箱是 glj0艾特outlook.com

PCB文件目前暂时不公开哈，可以根据开放的原理图文件自己画，体积增大两层板可以搞定

Gonglja, 2022-06-17:
好的，那我这边设计一下，感谢

Closed 2022-06-14.

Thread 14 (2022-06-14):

SW3526

Sirius-Cooper, 2022-06-14:
大佬你好，我U1的SW3526输入12V时可以正常工作，但是输入24V时接手机充电，电压就会一直快速的在5V和0V之前跳变，然后手机显示也是一直处于充电和未充电两个状态跳变。U2的SW3526是完全可以拉满正常使用的，我想问一下这大概会是什么问题，是芯片坏掉了吗还是电容耐压值不够，求解

liaozhelin, 2022-06-14:
> 大佬你好，我U1的SW3526输入12V时可以正常工作，但是输入24V时接手机充电，电压就会一直快速的在5V和0V之前跳变，然后手机显示也是一直处于充电和未充电两个状态跳变。U2的SW3526是完全可以拉满正常使用的，我想问一下这大概会是什么问题，是芯片坏掉了吗还是电容耐压值不够，求解

我觉得应该是焊接问题或者采样电阻吧，如果是有一组可以的话应该是有问题的那一组检测到过流触发保护之类的

Sirius-Cooper, 2022-06-14:
好的我试试采样电阻喝重新焊接

Closed 2022-06-15.

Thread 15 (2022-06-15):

question

ChinaCKKK, 2022-06-15:
up主您好
已经着手复刻您的项目了，遇到一点问题：3.3V DCDC稳压电路，RY8411芯片反馈电容是使用多大的呢，您的原理图上标注为NC，但是看您发的b站视频，是焊接上了的，所以特此请教up主，望解答，谢谢

liaozhelin, 2022-06-15:
这个可以焊接一个20p的电容，但是影响不大，所以我在bom中去掉了，环路我用示波器看还是挺稳定的

ChinaCKKK, 2022-06-15:
收到，谢谢up主，回复效率太高了，太感谢了
后续有问题可能还要叨扰您，再次感谢，视频已三连！！！

------------------&nbsp;原始邮件&nbsp;------------------
发件人:                                                                                                                        "liaozhelin/yds-charger"                                                                                    ***@***.***&gt;;
发送时间:&nbsp;2022年6月15日(星期三) 晚上9:51
***@***.***&gt;;
***@***.******@***.***&gt;;
主题:&nbsp;Re: [liaozhelin/yds-charger] question (Issue #15)

这个可以焊接一个20p的电容，但是影响不大，所以我在bom中去掉了，环路我用示波器看还是挺稳定的

—
Reply to this email directly, view it on GitHub, or unsubscribe.
You are receiving this because you authored the thread.Message ID: ***@***.***&gt;

liaozhelin, 2022-06-15:
谢谢，仓库中的信息有邮件提醒所以回复比较及时，后续制作中有啥问题再交流哈👀

ChinaCKKK, 2022-06-16:
up主你好，我今天开始下载固件了，遇到点问题：3.3v供电正常，使用的USB转TTL，把上面的器件全都卸下来了，使用杜邦线直接焊接上去的，连接板子的时候只连接了DP和GND，VCC并未连接（5V会烧esp32），然后板子使用DC供电，但是电脑并未成功识别

------------------&nbsp;原始邮件&nbsp;------------------
发件人:                                                                                                                        "liaozhelin/yds-charger"                                                                                    ***@***.***&gt;;
发送时间:&nbsp;2022年6月15日(星期三) 晚上9:57
***@***.***&gt;;
***@***.******@***.***&gt;;
主题:&nbsp;Re: [liaozhelin/yds-charger] question (Issue #15)

谢谢，仓库中的信息有邮件提醒所以回复比较及时，后续制作中有啥问题再交流哈👀

—
Reply to this email directly, view it on GitHub, or unsubscribe.
You are receiving this because you authored the thread.Message ID: ***@***.***&gt;

liaozhelin, 2022-06-16:
连接板子的时候只连接了DP和GND？是少打了嘛？

ChinaCKKK, 2022-06-16:
我就是只连接了中间两根数据线和GND，然后插上电脑，没有反应，已经重新换了一颗芯片了，还是这样，C15电容只有1.2V电压，3.3V供电正常

------------------&nbsp;原始邮件&nbsp;------------------
发件人:                                                                                                                        "liaozhelin/yds-charger"                                                                                    ***@***.***&gt;;
发送时间:&nbsp;2022年6月16日(星期四) 上午9:32
***@***.***&gt;;
***@***.******@***.***&gt;;
主题:&nbsp;Re: [liaozhelin/yds-charger] question (Issue #15)

连接板子的时候只连接了DP和GND？是少打了嘛？

—
Reply to this email directly, view it on GitHub, or unsubscribe.
You are receiving this because you authored the thread.Message ID: ***@***.***&gt;

liaozhelin, 2022-06-16:
重点检查下晶振得焊接，可以去掉晶振两个匹配电容试试，C15为1.5v说明芯片没有正常启动

ChinaCKKK, 2022-06-16:
我是这样接线的，不知道这样对不对

------------------&nbsp;原始邮件&nbsp;------------------
发件人:                                                                                                                        "liaozhelin/yds-charger"                                                                                    ***@***.***&gt;;
发送时间:&nbsp;2022年6月16日(星期四) 上午9:38
***@***.***&gt;;
***@***.******@***.***&gt;;
主题:&nbsp;Re: [liaozhelin/yds-charger] question (Issue #15)

重点检查下晶振得焊接，可以去掉晶振两个匹配电容试试，C15为1.5v说明芯片没有正常启动

—
Reply to this email directly, view it on GitHub, or unsubscribe.
You are receiving this because you authored the thread.Message ID: ***@***.***&gt;

galamygod, 2022-06-17:
老哥，我把6525换成了6505，现在上电9v有七百毫安，去掉u3有一百多毫安，连接dp和dm电脑一点反应没有

galamygod, 2022-06-17:
我又换了一个6505（u8），现在电压9v，电流为16毫安，但是连接电脑没反应，是我驱动问题吗

galamygod, 2022-06-17:
现在排查出的问题就是只要装上u3就会大电流

liaozhelin, 2022-06-17:
> 现在排查出的问题就是只要装上u3就会大电流

IP6525的和连接电脑关系不大，你最好检查一下IP6525和IP6505是不是可以pintopin替换的，正常待机电流在12V时候应该是在30mA左右，驱动的话我仓库里有，得安装才行

liaozhelin, 2022-06-17:
> 老哥，我把6525换成了6505，现在上电9v有七百毫安，去掉u3有一百多毫安，连接dp和dm电脑一点反应没有

重点检查是否有虚焊，以及晶振电路和电源电路，满足这两个条件应该就可以检测到

liaozhelin, 2022-06-17:
> 我是这样接线的，不知道这样对不对
> […](#)
> ------------------&nbsp;原始邮件&nbsp;------------------ 发件人: "liaozhelin/yds-charger" ***@***.***&gt;; 发送时间:&nbsp;2022年6月16日(星期四) 上午9:38 ***@***.***&gt;; ***@***.******@***.***&gt;; 主题:&nbsp;Re: [liaozhelin/yds-charger] question (Issue #15) 重点检查下晶振得焊接，可以去掉晶振两个匹配电容试试，C15为1.5v说明芯片没有正常启动 — Reply to this email directly, view it on GitHub, or unsubscribe. You are receiving this because you authored the thread.Message ID: ***@***.***&gt;

好像没看到您是怎么接线的，主要应该还是上面所说的那些问题

ChinaCKKK, 2022-06-17:
好的，我再去检查检查。大三考研党，没啥时间专门弄这个，也就是闲余时间弄一下。感谢up主

------------------&nbsp;原始邮件&nbsp;------------------
发件人:                                                                                                                        "liaozhelin/yds-charger"                                                                                    ***@***.***&gt;;
发送时间:&nbsp;2022年6月17日(星期五) 晚上6:46
***@***.***&gt;;
***@***.******@***.***&gt;;
主题:&nbsp;Re: [liaozhelin/yds-charger] question (Issue #15)

我是这样接线的，不知道这样对不对
 …
 ------------------&nbsp;原始邮件&nbsp;------------------ 发件人: "liaozhelin/yds-charger" @.&gt;; 发送时间:&nbsp;2022年6月16日(星期四) 上午9:38 @.&gt;; @.@.&gt;; 主题:&nbsp;Re: [liaozhelin/yds-charger] question (Issue #15) 重点检查下晶振得焊接，可以去掉晶振两个匹配电容试试，C15为1.5v说明芯片没有正常启动 — Reply to this email directly, view it on GitHub, or unsubscribe. You are receiving this because you authored the thread.Message ID: @.***&gt;

好像没看到您是怎么接线的，主要应该还是上面所说的那些问题

—
Reply to this email directly, view it on GitHub, or unsubscribe.
You are receiving this because you authored the thread.Message ID: ***@***.***&gt;

galamygod, 2022-06-18:
> > 老哥，我6525换成6505，现在上电9v有七百毫安，把u3有一百多毫安删除，连接dp和dm电脑一点反应没有
>
> 重点检查是否有虚焊，以及晶振电路和电源电路，满足这两个条件应该就可以检测到

电源电路是没有问题的，3.3已经有了，我是用dc供电，然后USB中间两条接到板子上，驱动我双击以后会闪退，我也不知道安装成功没有

liaozhelin, 2022-06-20:
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

如果双击闪退，可以去官网下载自己平台的对应驱动，以管理员模式运行

Closed 2022-06-17.

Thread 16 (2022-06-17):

更改设计

Gonglja, 2022-06-17:
up您好
看了下里面没有pcb文件，方便发下嘛，需要改下设计
我的邮箱是 glj0艾特outlook.com

_Originally posted by @Gonglja in https://github.com/liaozhelin/yds-charger/issues/13#issuecomment-1158735782_

liaozhelin, 2022-06-17:
已经在其他issue回复

Closed 2022-06-17.

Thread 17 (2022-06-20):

插电脑上一直提示未识别的usb设备

Dustl1ght, 2022-06-20:
UP你好，我焊接完然后插电脑上就一直提示未识别的usb设备，是不是跟晶振有关系，我查资料说要用40MHz的无源晶振，我用的有源晶振。

liaozhelin, 2022-06-20:
> UP你好，我焊接完然后插电脑上就一直提示未识别的usb设备，是不是跟晶振有关系，我查资料说要用40MHz的无源晶振，我用的有源晶振。

呃，我用的是无源的，有源的应该需要修改电路变成单端，可以换成无源的试试

Dustl1ght, 2022-06-20:
好的好的谢谢大佬，我买了无源的，在路上了

Dustl1ght, 2022-06-21:
up您好，我人麻了，第一个问题：这个充电器是不是就算不烧录程序，只要所有元器件正常焊接也是可以输出电压的？
第二个问题：我焊接好了全部的元器件，然后发现背面中间的那个A口不能充电，其他的3个口均能充电，于是我就想用万用表量一下是哪个电压没出来，我把表笔往其中一个6525上一放，紧接着啪的一声，然后就是一个火光，炸了一个SI2309，于是我赶紧断电，换了一个2309，然后发现那个6525也烧了，于是我又换了一个6525，然后再上电，直接烧了保险，保险是125V 3A的，我人麻了我接下来是修一修还是说再重新焊个板子。。。。。。

Dustl1ght, 2022-06-21:
> > up您好，我人麻了，第一个问题：这个充电器是不是就算不烧录程序，只要所有元器件正常焊接也是可以输出电压的？ 第二个问题：我焊接好了全部的元器件，然后发现背面中间的那个A口不能充电，其他的3个口均能充电，于是我就想用万用表量一下是哪个电压没出来，我把表笔往其中一个6525上一放，紧接着啪的一声，然后就是一个火光，炸了一个SI2309，于是我赶紧断电，换了一个2309，然后发现那个6525也烧了，于是我又换了一个6525，然后再上电，直接烧了保险，保险是125V 3A的，我人麻了我接下来是修一修还是说再重新焊个板子。。。。。。
>
> 1.是的 2.直接烧6525的我没见过，感觉你可以检查下输出部分是否短路，还有采样环路电阻是否正常，SI2309是控制6525上电的，如果这个炸了说明6525输入部分有短路，也重点检查下输入部分是否有短路情况 PS：整体电路很简单的，这个问题炸器件大概率是短路，重点检查下各部分的阻值，不要盲目瞎换器件，跟着输入查找应该很快能找到问题

谢谢up！！！等明天新的晶振到了我重新做一个试试，我买了至少5套元器件哈哈哈哈，毕竟第一次焊贴片，尽管有热台，用的还是低温锡，还是出了大问题哈哈哈哈，焊过一次就有经验了，等我成功一个我再回头修一下这个坏的

2905058350, 2022-07-04:
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

可以给个bom购买参考吗我有些找不到

Dustl1ght, 2022-07-05:
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

你具体哪个东西买不到，我都是在立创商城和淘宝上一个一个搜的，你需要结合料号和封装自己筛选

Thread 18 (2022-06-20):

boom配件，与

rambodoctor, 2022-06-20:
大佬，请问active boom 的文件该如何使用，小小白正打算复刻你的作品，板子完成打样，正在为boom 的问题发愁  ，另外怎么知道pcb上放置该哪些电容电阻件嘛。  另外大佬如果需要服务器存放升级文件，或者转发天气什么的 ， 我可以提供一台服务器，也可以帮忙采集天气。

liaozhelin, 2022-06-20:
> 大佬，请问active boom 的文件该如何使用，小小白正打算复刻你的作品，板子完成打样，正在为boom 的问题发愁  ，另外怎么知道pcb上放置该哪些电容电阻件嘛。  另外大佬如果需要服务器存放升级文件，或者转发天气什么的 ， 我可以提供一台服务器，也可以帮忙采集天气。

你好，动态bom直接浏览器打开就可以使用了，至于怎么摆放器件就是根据bom就可以了，看位号。服务器的话我自己有，正在开发中，感谢你的好意了～

Closed 2022-06-21.

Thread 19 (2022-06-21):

老哥求救 上层版的问题

Zyilin98, 2022-06-21:
在我烧了两个ESP32 + 两个SW3526 + N个加速度传感器 等等之后 终于写进去固件并且触发快充了
但是 上层版 这里两个led灯也不亮 拨码开关每次在写固件的时候才有效（也许无效但是确实是写进去了固件）
很多功能还是没用办法用 请问一下老哥 这个拨码开关是如何鉴别能正常用的 我已经换了好几个了 还是不能用

liaozhelin, 2022-06-21:
> 在我烧了两个ESP32 + 两个SW3526 + N个加速度传感器 等等之后 终于写进去固件并且触发快充了 但是 上层版 这里两个led灯也不亮 拨码开关每次在写固件的时候才有效（也许无效但是确实是写进去了固件） 很多功能还是没用办法用 请问一下老哥 这个拨码开关是如何鉴别能正常用的 我已经换了好几个了 还是不能用

呃呃，上层LED不亮下层亮应该就是焊接或者排针问题

Closed 2022-06-21.

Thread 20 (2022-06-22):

配网连接WiFi的问题 一些小问题

Zyilin98, 2022-06-22:
昨天解决完硬件问题之后就开始配网 然后发现一个问题 就是配网之后 显示的ip 既不是我这里的公网ip 也不是内网ip 但是路由器网关哪里也确实是查到了这个设备在线
手动OTA固件就会卡住不动 没有反应。

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

然后 topBoard这个pcb原来是单层板么 单层板就没法嫖嘉立创紫 😂

Zyilin98, 2022-06-22:
去重刷了固件 还是一样的问题 获取的ip不对 手动没法ota(还是说这个功能没做) 我刷的是合并固件

michael6555, 2022-06-22:
请问你的也是不是板子上预留给显示屏的位置不对？

Zyilin98, 2022-06-22:
我这就感觉屏线短了点 把显示屏弯成直角感觉有点费劲 怕把屏搞坏

---原始邮件---
发件人: ***@***.***&gt;
发送时间: 2022年6月22日(周三) 中午12:18
收件人: ***@***.***&gt;;
抄送: ***@***.******@***.***&gt;;
主题: Re: [liaozhelin/yds-charger] 配网连接WiFi的问题 一些小问题 (Issue #20)

请问你的也是不是板子上预留给显示屏的位置不对？

—
Reply to this email directly, view it on GitHub, or unsubscribe.
You are receiving this because you authored the thread.Message ID: ***@***.***&gt;

liaozhelin, 2022-06-22:
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

1.这个IP我是用的乐鑫的方法直接读的，我后面验证下，你这个看起来像获取导公网IP了

Zyilin98, 2022-06-22:
1.这个IP怎么看也不像是公网ip 这个ip查过去是美国AT&T 就很头秃 我感觉是哪里逻辑有问题
2.可能是表达问题吧 是铝外壳的前面板和后面板的pcb 这个好像就后面版是双层板 前面板好像是单层板
3.屏线这个我对的是屏线的两个洞对pcb上的洞 还是感觉屏线短了点 下次我自己焊接的时候看看能不能挪一挪
4.OTA服务器在Github么 也许我还得用网关级代理......   路由器之前为了别的智能设备关了双频合一  一会试试光猫自己的2.4Gwifi 再不行 我也就没办法了 看看新的固件版本会不会好一点
issue就不用开启了 能回复就行 谢谢老哥

对了，老哥有没有交流群之类的 这样就省的好多事开issue了

liaozhelin, 2022-06-22:
> 1.这个IP怎么看也不像是公网ip 这个ip查过去是美国AT&T 就很头秃 我感觉是哪里逻辑有问题 2.可能是表达问题吧 是铝外壳的前面板和后面板的pcb 这个好像就后面版是双层板 前面板好像是单层板 3.屏线这个我对的是屏线的两个洞对pcb上的洞 还是感觉屏线短了点 下次我自己焊接的时候看看能不能挪一挪 4.OTA服务器在Github么 也许我还得用网关级代理...... 路由器之前为了别的智能设备关了双频合一 一会试试光猫自己的2.4Gwifi 再不行 我也就没办法了 看看新的固件版本会不会好一点 issue就不用开启了 能回复就行 谢谢老哥
>
> 对了，老哥有没有交流群之类的 这样就省的好多事开issue了

1.呃，这个IP的问题我也不太清除，我这里看看能不能复现，因为我试了用wifi和手机热点获取到的都是本地ip，这个问题后面研究下

Closed 2022-06-22.

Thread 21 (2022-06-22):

人麻了，连接电脑一点反应没有，esp32有3.3v,但是C15只有2.8V

galamygod, 2022-06-22:

galamygod, 2022-06-22:
而且4个输出口都没有电压

galamygod, 2022-06-23:
> 去检测一下晶振 看看晶振是不是正常起振 或者简单一点 看看晶振方向是不是对了 四个口都没电压很正常 如果晶振和周边电路都正常 建议就换一块esp32

我靠，晶振分方向的吗

Zyilin98, 2022-06-23:
咋不分方向 你以为是对称的么 😂 我当初因为没分就烧了一颗esp 应该让作者下次标一下正确方向 应该正确的方向是 40mhz 这个丝印朝着usb外接针的方向 我买的是这样 具体的还得你自己拿万用表试 四个触点有两个是地线 呈对角线的

---原始邮件---
发件人: ***@***.***&gt;
发送时间: 2022年6月23日(周四) 上午9:12
收件人: ***@***.***&gt;;
抄送: ***@***.******@***.***&gt;;
主题: Re: [liaozhelin/yds-charger] 人麻了，连接电脑一点反应没有，esp32有3.3v,但是C15只有2.8V (Issue #21)

去检测一下晶振 看看晶振是不是正常起振 或者简单一点 看看晶振方向是不是对了 四个口都没电压很正常 如果晶振和周边电路都正常 建议就换一块esp32

我靠，晶振分方向的吗

—
Reply to this email directly, view it on GitHub, or unsubscribe.
You are receiving this because you commented.Message ID: ***@***.***&gt;

galamygod, 2022-06-23:
> 咋不分方向 你以为是对称的么 😂 我当初因为没分就烧了一颗esp 应该让作者下次标一下正确方向 应该正确的方向是 40mhz 这个丝印朝着usb外接针的方向 我买的是这样 具体的还得你自己拿万用表试 四个触点有两个是地线 呈对角线的
> […](#)
> ---原始邮件--- 发件人: ***@***.***&gt; 发送时间: 2022年6月23日(周四) 上午9:12 收件人: ***@***.***&gt;; 抄送: ***@***.******@***.***&gt;; 主题: Re: [liaozhelin/yds-charger] 人麻了，连接电脑一点反应没有，esp32有3.3v,但是C15只有2.8V (Issue #21) 去检测一下晶振 看看晶振是不是正常起振 或者简单一点 看看晶振方向是不是对了 四个口都没电压很正常 如果晶振和周边电路都正常 建议就换一块esp32 我靠，晶振分方向的吗 — Reply to this email directly, view it on GitHub, or unsubscribe. You are receiving this because you commented.Message ID: ***@***.***&gt;

现在Q2输出12v（也就是u3有电压，usb3能正常输出），Q3没有电压（相对应的u8没有电压，USB8不能正常输出）

Zyilin98, 2022-06-24:
因为我这边这个双A口电路的大概原理也没看明白 至少我实验的情况是 esp32没正常工作之前 两个A口是没输出的
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
研究了一下电路图和原理图 LMBT3904的中间两个脚通过1K电阻之后 直接连到了esp的这两个U0TXD 和U0RXD上 虽然我确实是不知道为什么要接这.....😅 具体还得问作者

Zyilin98, 2022-06-24:
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

因为我这边这个双A口电路的大概原理也没看明白 至少我实验的情况是 esp32没正常工作之前 两个A口是没输出的
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
研究了一下电路图和原理图 LMBT3904的中间两个脚通过1K电阻之后 直接连到了esp的这两个U0TXD 和U0RXD上 虽然我确实是不知道为什么要接这.....😅 具体还得问作者

liaozhelin, 2022-06-25:
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

是的，这个电路是IO高电平就控制通断，因为C3端口紧张（都用光了）所以复用了串口作为IO，当需要作为下载的时候也不影响，主要是想实现全部端口的控制，前面两个C口也可以通过软件控制通断，后面的A口如果是接一些台灯之类的设备可以实现自动开关灯，主要是这么想的，具体的web界面最近在写了hhhh

liaozhelin, 2022-06-25:
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

一个USBA有电压一个没有的话，建议查看 LMBT3904是不是买错了

Zyilin98, 2022-06-25:
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

我之前也是一个有一个没有 换了板子 换了一颗也就好了 这个件还好我买的多.......... 现在也是A口输出有点问题 打算等有空换换ip6525试试
对了 作者有没有计划 接口握手不通的快充 led显示不同的颜色 的计划 没输出的时候是绿色呼吸/蓝色呼吸 正常5V的时候是绿色呼吸 握手pd协议高电压的时候（例如12V及以上的时候）是红灯呼吸。

liaozhelin, 2022-06-25:
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

有的，您和我想的一样，这个也是我设计四个RGB灯的初衷，四个RGB分别对应快充的四种状态，这个功能加上去很快，应该会在下一版和WEB控制界面一起推出，最近考试事情比较多，要不然之前那一版本就加上了hhh✌

galamygod, 2022-06-30:
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

昨天搞好两块板子（3.3v有，插电脑提示有连接，但是公司电脑装驱动失败），稳压电源上电都没有问题，就拿回宿舍烧录，用的坠机堡垒电源19V-6.5A，结果插上电过一会3904燃起来了，没敢试第二块

galamygod, 2022-06-30:
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

昨天搞好两块板子（3.3v有，插电脑提示有连接，但是公司电脑装驱动失败），稳压电源上电都没有问题，就拿回宿舍烧录，用的坠机堡垒电源19V-6.5A，结果插上电过一会3904燃起来了，没敢试第二块

Zyilin98, 2022-06-30:
一般系统够新驱动就不用装

3904要是老烧就别焊了 si2309直接把锡连上&nbsp;
这边的电路是一个三极管一个mos管拿来通过单片机控制ip6525开关的

---原始邮件---
发件人: ***@***.***&gt;
发送时间: 2022年6月30日(周四) 上午10:47
收件人: ***@***.***&gt;;
抄送: ***@***.******@***.***&gt;;
主题: Re: [liaozhelin/yds-charger] 人麻了，连接电脑一点反应没有，esp32有3.3v,但是C15只有2.8V (Issue #21)

咋不分方向 你以为是对称的么 😂 我当初因为没分就烧了一颗esp 应该让作者下次标一下正确方向 应该正确的方向是 40mhz 这个丝印朝着usb外接针的方向 我买的是这样 具体的还得你自己拿万用表试 四个触点有两个是地线 呈对角线的
 …
 ---原始邮件--- 发件人: @.&gt; 发送时间: 2022年6月23日(周四) 上午9:12 收件人: _@**._&gt;; 抄送: ***@***.***@._&gt;; 主题: Re: [liaozhelin/yds-charger] 人麻了，连接电脑一点反应没有，esp32有3.3v,但是C15只有2.8V (Issue #21) 去检测一下晶振 看看晶振是不是正常起振 或者简单一点 看看晶振方向是不是对了 四个口都没电压很正常 如果晶振和周边电路都正常 建议就换一块esp32 我靠，晶振分方向的吗 — Reply to this email directly, view it on GitHub, or unsubscribe. You are receiving this because you commented.Message ID: _@_.*&gt;

现在Q2输出12v（也就是u3有电压，usb3能正常输出），Q3没有电压（相对应的u8没有电压，USB8不能正常输出）

一个USBA有电压一个没有的话，建议查看 LMBT3904是不是买错了（看看是否买到了3946）

昨天搞好两块板子（3.3v有，插电脑提示有连接，但是公司电脑装驱动失败），稳压电源上电都没有问题，就拿回宿舍烧录，用的坠机堡垒电源19V-6.5A，结果插上电过一会3904燃起来了，没敢试第二块

—
Reply to this email directly, view it on GitHub, or unsubscribe.
You are receiving this because you commented.Message ID: ***@***.***&gt;

Closed 2022-06-25.

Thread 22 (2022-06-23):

关于bom

gxq-is-a-lovely-girl, 2022-06-23:
在底板的bom中C1,C4,C44,C61,C65为一类，在元器件采购指南中C１,C44归为直插固态电容,而C65,C61,C4与C59,C60归为高频低阻直插铝电解电容,我应该按哪个?还有貌似C1,C44(220uf/35V)的尺寸大小bom中没有写是几成几,小白提问勿喷.

Zyilin98, 2022-06-25:
这个东西 我怎么说 具体还得等作者回答 我自己的意见是 SW3526 和ip6525的示例电路中没标注非得是固态电容还是铝电解电容
我自己正好有点余料 刚开始做的是固态和电解混用 后来就是全换固态电容了 看那些做成的大佬 也是电解的多
至于220uf的这个尺寸 我买的是8*11.5MM固态电容 之前库存的是8*12MM的电解电容

Zyilin98, 2022-06-25:
> 这个选料具体还得等作者回答
我自己的意见是 SW3526 和ip6525的示例电路中没标注非得是固态电容还是铝电解电容 我自己正好有点余料 刚开始做的是固态和电解混用 后来就是全换固态电容了 看那些做成的大佬 也是电解的多 至于220uf的这个尺寸 我买的是8_11.5MM固态电容 之前库存的是8_12MM的电解电容

liaozhelin, 2022-06-25:
> 在底板的bom中C1,C4,C44,C61,C65为一类，在元器件采购指南中C１,C44归为直插固态电容,而C65,C61,C4与C59,C60归为高频低阻直插铝电解电容,我应该按哪个?还有貌似C1,C44(220uf/35V)的尺寸大小bom中没有写是几成几,小白提问勿喷.

我自己的话就只有C口输出的两个电容用了固态电容，其他都是普通铝电解电容，具体物料购买地址我记得我有附在采购指南中，您可以去看看

Closed 2022-06-25.

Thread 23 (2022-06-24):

大佬，求指教，RY8411出来电压一直在3.7以上

xiyuxixi, 2022-06-24:
仅焊接原理图中的 输入模块和 3.3V降压模块。 5V输入测试RY8411输出3.7V多。12V的时候在3.5V多。20V输入又上升到3.8V输出。换了好几个RY8411都一样

ktx888, 2022-06-25:
看你这描述不知道是怎么回事，不过我的可以稳定在3.3v

Zyilin98, 2022-06-25:
建议拍个图片出来看看

liaozhelin, 2022-06-25:
是的，这个电路很多人焊接后都没有问题，建议还是检查下器件是不是焊接有误

Closed 2022-06-25.

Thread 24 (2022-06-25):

电感L1发热

gzzz2008, 2022-06-25:
电压不正常，而且电感L1 上电一会就发热了。

gzzz2008, 2022-06-25:
还有能发一份能有电路连接的动态BOM图吗？这样好排查原因。

gzzz2008, 2022-06-25:
还有为什么没有接地呢？

liaozhelin, 2022-06-25:
> 还有能发一份能有电路连接的动态BOM图吗？这样好排查原因。

嘉立创的动态bom插件貌似有bug，我导出是空文件，所以之前用的是脚本导出，您邮箱发我个我给你发下源文件，您那里导出试试

liaozhelin, 2022-06-25:
> 还有为什么没有接地呢？

CDEP电感第三个脚是固定而不是屏蔽，因此不用接低，电感发烫说明输出环路有问题，重点检查下芯片sw引脚和反馈引脚

gzzz2008, 2022-06-25:
> > 还有能发一份能有电路连接的动态BOM图吗？这样好排查原因。
>
> 嘉立创的动态bom插件貌似有bug，我导出是空文件，所以之前用的是脚本导出，您邮箱发我个我给你发下源文件，您那里导出试试

59029226@qq.com

Closed 2022-06-25.

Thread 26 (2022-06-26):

显示屏接线相关优化

Zyilin98, 2022-06-26:
现在的pcb和显示屏之间是靠焊接 连接 而且现在屏线有长有短 经常有屏线够不到或者弯不过来的情况
就能不能改一下显示屏的接线方式
适配这种接线方式
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
我知道这种母座有点难焊
但是最起码可以减小焊接屏幕的损耗 将来屏幕坏了也方便更换

ktx888, 2022-06-26:
1、借楼吐槽一下，我之前就买的这家的30pin的那款显示屏，边框大了一圈，根本装不进去，后来换了一家。
2、我觉得楼主提的也有道理。不过这个显示屏应该也不至于用着用着就坏了吧（我猜的）。
3、up主好像还没有发布新的固件，我自己改了代码，我的支持1分钟无操作自动息屏，也能保护屏幕。我还加了天气预报功能。如果有需要可以找我要，哈哈😃

Zyilin98, 2022-06-26:
> 1、借楼吐槽一下，我之前就买的这家的30pin的那款显示屏，边框大了一圈，根本装不进去，后来换了一家。 2、我觉得楼主提的也有道理。不过这个显示屏应该也不至于用着用着就坏了吧（我猜的）。 3、up主好像还没有发布新的固件，我自己改了代码，我的支持1分钟无操作自动息屏，也能保护屏幕。我还加了天气预报功能。如果有需要可以找我要，哈哈😃

卧槽 我买的就是这家 卧槽了 能给一下你那个新一家的屏幕链接么

ktx888, 2022-06-26:
【淘宝】https://m.tb.cn/h.fwWEmZ6?tk=Bq9x2or860c「0.96寸OLED显示屏 窄边框128*64点阵SSD1315驱动30PIN兼容SSD1306」
点击链接直接打开

Zyilin98, 2022-06-26:
> 【淘宝】[https://m.tb.cn/h.fwWEmZ6?tk=Bq9x2or860c「0.96寸OLED显示屏](https://m.tb.cn/h.fwWEmZ6?tk=Bq9x2or860c%E3%80%8C0.96%E5%AF%B8OLED%E6%98%BE%E7%A4%BA%E5%B1%8F) 窄边框128*64点阵SSD1315驱动30PIN兼容SSD1306」 点击链接直接打开

感谢 这个屏线应该不会很短吧

ktx888, 2022-06-26:
>

不短，正好

ktx888, 2022-06-26:
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

Zyilin98, 2022-06-26:
> 1、借楼吐槽一下，我之前就买的这家的30pin的那款显示屏，边框大了一圈，根本装不进去，后来换了一家。 2、我觉得楼主提的也有道理。不过这个显示屏应该也不至于用着用着就坏了吧（我猜的）。 3、up主好像还没有发布新的固件，我自己改了代码，我的支持1分钟无操作自动息屏，也能保护屏幕。我还加了天气预报功能。如果有需要可以找我要，哈哈😃

对了老哥 我顺带要一份固件吧 试试这个气象站 顺带也看一下我这是不是配网还有问题

ktx888, 2022-06-26:
> > 1、借楼吐槽一下，我之前就买的这家的30pin的那款显示屏，边框大了一圈，根本装不进去，后来换了一家。 2、我觉得楼主提的也有道理。不过这个显示屏应该也不至于用着用着就坏了吧（我猜的）。 3、up主好像还没有发布新的固件，我自己改了代码，我的支持1分钟无操作自动息屏，也能保护屏幕。我还加了天气预报功能。如果有需要可以找我要，哈哈😃
>
> 对了老哥 我顺带要一份固件吧 试试这个气象站 顺带也看一下我这是不是配网还有问题

你加我qq吧，烧程序可能有一些bug，好交流（1760489926）

Runeluna, 2022-06-29:
> 【淘宝】[https://m.tb.cn/h.fwWEmZ6?tk=Bq9x2or860c「0.96寸OLED显示屏](https://m.tb.cn/h.fwWEmZ6?tk=Bq9x2or860c%E3%80%8C0.96%E5%AF%B8OLED%E6%98%BE%E7%A4%BA%E5%B1%8F) 窄边框128*64点阵SSD1315驱动30PIN兼容SSD1306」 点击链接直接打开

谢谢老哥，我搞的另一家也是大了一圈

liaozhelin, 2022-06-29:
这个提议不错，有想自行修改的可以私发我下邮箱，我私发源文件。之前设计的时候我主要是用手头现有的屏幕，所以没有考虑这种接口的形式，果然做的人多考虑的事情就更加周全了👍

Zyilin98, 2022-06-29:
> 这个提议不错，有想自行修改的可以私发我下邮箱，我私发源文件。之前设计的时候我主要是用手头现有的屏幕，所以没有考虑这种接口的形式，果然做的人多考虑的事情就更加周全了👍

我去试试看看能不能换种接口 但是主要是怕出现那种显示屏装不上的问题 我看看咋优化这个pcb板子的开口吧 我看周边应该没电路可能就是led那边的线可能要稍微挪挪 多切一点影响应该不大 我先试试

blacksr, 2022-07-23:
！！我也买了这家！然后发现大了一圈，但是一直没管这个问题，将就用了，这就去换！

blacksr, 2022-07-23:
！！我也买了这家！然后发现大了一圈，但是一直没管这个问题，将就用了，这就去换！

Closed 2022-06-29.

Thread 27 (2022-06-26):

串口

chjdbh, 2022-06-26:
上电会出现串口一秒后消失再过一秒又会出现一直重复这样

ktx888, 2022-06-26:
>

拨盘往左拨之后再上电

chjdbh, 2022-06-27:
还是不行

ktx888, 2022-06-27:
按道理来说不应该，我之前也和你一样一直跳，但是我把排针中间那排最下面的引脚对地短接后（也就相当于拨盘向左拨），再上电就不跳了

Dustl1ght, 2022-06-27:
> 上电会出现串口一秒后消失再过一秒又会出现一直重复这样

我之前也是这样，我换了个无源晶振就好了，之前用的有源晶振，不知道你是不是和我一样的问题

Zyilin98, 2022-06-27:
我之前也有这个问题 加焊了一下usb线和接头 顺带对调了中间的数据线 也好了 不知道是不是这样的问题
也许你得检查一下esp32的3.3V供电

gzzz2008, 2022-07-05:
上电后，串口不显示，一点反应都没有，是怎么回事呢？是我操作顺序有问题？

Closed 2022-06-29.

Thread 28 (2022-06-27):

芯片配网

Dustl1ght, 2022-06-27:
up大大你好，现在我遇到个问题是无法配网，2.4g频段也不行，我用的路由器是wifi6的，我看网上说esp32不支持最新的wifi协议，然后就是配网失败之后就不能再重新配网了，需要重新刷固件才可以

ktx888, 2022-06-27:
兄弟我这有我修改过的固件，在up没更新前可以过渡，如果需要加我QQ发给你1760489926

Dustl1ght, 2022-06-27:
> 兄弟我这有我修改过的固件，在up没更新前可以过渡，如果需要加我QQ发给你1760489926

多谢

Zyilin98, 2022-06-27:
wifi6的路由器关掉多频合一 双频优选 等等 暴露出2.4GWiFi试试

Dustl1ght, 2022-06-27:
> wifi6的路由器关掉多频合一 双频优选 等等 暴露出2.4GWiFi试试

好的好的，我试试

Closed 2022-06-28.

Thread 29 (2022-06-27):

上电后有声音

gzzz2008, 2022-06-27:
插上电源后，总是有吱吱的声音，这是正常吗？不知道什么发的声音，电压总是3.2V，没有3.3V ，烧录不上程序，插电脑没有反应。

Zyilin98, 2022-06-28:
emmm 感觉是哪里短路了 排查一下ip6525T LMBT3904 sw3526本体 type-c接口有没有连锡或者短路
3.3出3.2  3.4都很正常 不是非得要3.3 不过差太多了之后 还是得检测一下哪里有没有焊接问题

Sirius-Cooper, 2022-06-29:
RY8411发热嘛，要不看一下芯片供电正不正常，声音可能是某个电感啸叫（？），几个大电感除了电源芯片就是RY8411那个电感了，看下是不是那里的问题

liaozhelin, 2022-06-29:
主要还是查看下是否存在短路情况，正常空载情况下应该是没有声音的才对，插电脑烧录没有反应可以查看下其他的issues

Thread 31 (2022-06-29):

[硬件] BOM的型号和实际好像有出入

Runeluna, 2022-06-29:
买元件的过程中发现BOM的型号和实际好像有出入，比如C4在bom标注的是220uF，看购买说明上好像是100uF，这个有影响吗，以哪个为准？
还有我看到有一个保险丝座，请问下保险丝选哪种规格，多少V和A的，谢谢

Dustl1ght, 2022-06-29:
> 买元件的过程中发现BOM的型号和实际好像有出入，比如C4在bom标注的是220uF，看购买说明上好像是100uF，这个有影响吗，以哪个为准？ 还有我看到有一个保险丝座，请问下保险丝选哪种规格，多少V和A的，谢谢

我全部按照bom买的，目前没有出现问题，保险丝座嘉立创搜索0154007.DR，总之保险丝座就长这样。保险的规格我一开始用的125V 3A 上电就烧，我后来直接上了125V 10A。这个0154007.DR是7A的，我觉得应该也没问题。

liaozhelin, 2022-06-29:
是的，大部分应该是对的上的，其实也没有多少料，主要是用LCEDA直接生成，应该按照料号都可以找到

Closed 2022-06-29.

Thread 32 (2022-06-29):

LMBT3904双三极管发热严重

Sirius-Cooper, 2022-06-29:
大佬你好，我想问一下LMBT3904双三极管上电之后发热严重是正常现象吗，上电之后空载发热严重，烫手的那种，但是系统可以正常使用

ktx888, 2022-06-29:
我也会，我现在已经把3904拆了

liaozhelin, 2022-06-29:
可以修改3904的上拉电阻到10K就可以了

galamygod, 2022-06-29:
>

我的3904已经烧冒烟了

ktx888, 2022-06-30:
> 我的3904已经烧冒烟了

我3904着过火你敢信，明火

galamygod, 2022-07-02:
> > 我的3904已经烧冒烟了
>
> 我3904着过火你敢信，明火

我的就是插笔记本电源，然后两秒钟的火，还带声音的，然后就是冒烟

XiDD93, 2022-07-04:
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
我也是接笔记本电源烧了，在我手中直接炸开了，但是充电功能好像不受影响，你找到问题原因了吗？

galamygod, 2022-07-06:
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

还没呢，我连程序都还没烧录成功，一直弹USB有问题

e1585742133, 2022-07-09:
检查  一下SI2309  是不是卖家发错货了     我遇见过一样的问题    重新换了SI2309  就好了

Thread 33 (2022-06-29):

分享固件

ktx888, 2022-06-29:
https://wwd.lanzout.com/it6bO07449je
这是我在作者基础之上修改的程序，有需要的可以下载
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

https://user-images.githubusercontent.com/78667688/176445395-e5bfbad2-1bec-4cf9-8f73-0b44ffdd2aef.MOV

liaozhelin, 2022-06-29:
厉害了！天气预报这个功能很实用，还带有上位机，完成度很高了👍最近鸽得有点久，大家可以根据自己的需要修改适合自己的固件，也可以试一下这些大神们的固件，丰富各种玩法，这个issue就不close了，让更多人可以看到✔

mornlena, 2022-07-01:
刷了，很赞~

ktx888, 2022-07-02:
> 刷了，很赞~

哈哈😃

e1585742133, 2022-07-08:
我刷了  黑屏 指示灯也不亮

xiaoqingnian20, 2022-07-09:
刷了，卡wifi初始化

ktx888, 2022-07-09:
开机不停按确认键能进配网

X131402, 2022-07-09:
charger这个软件连接不上，我用udp测试工具是可以通讯的，也有返回功率和电压信息。这是怎么回事

X131402, 2022-07-09:
是1.1那个版本连不上，然后led不亮设置不了

ktx888, 2022-07-09:
试一下charger1.2

X131402, 2022-07-09:
可以连上了，是防火墙那边的问题，但是led不亮了设置了也没反应

ktx888, 2022-07-09:
加QQ吧，这地方回答好麻烦  1760489926

e1585742133, 2022-07-11:
感谢大佬的默默付出

blacksr, 2022-08-11:
感谢dalao的分享！固件刷上了孩子很爱吃

Inevitableofcold, 2022-09-06:
问下3904的两个上拉电阻修改成什么电阻了，哪里可以查看，谢谢O(∩_∩)O

blacksr, 2022-09-06:
> 问下3904的两个上拉电阻修改成什么电阻了，哪里可以查看，谢谢O(∩_∩)O

修改成10K了，BOM表中已经更新过来了，按照最新的BOM表贴就可以了

Inevitableofcold, 2022-09-06:
> > 问下3904的两个上拉电阻修改成什么电阻了，哪里可以查看，谢谢O(∩_∩)O
>
> 修改成10K了，BOM表中已经更新过来了，按照最新的BOM表贴就可以了

问下有两个10uf/35V的C0805贴片电阻买的是25V耐压值的，贴上会不会不能用，谢谢回答

blacksr, 2022-09-06:
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

如果是bom标了耐压值要求的最好上对应的，高了可以的 低了估计会烧板，这里面电路我也不太懂

blacksr, 2022-09-06:
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

看了一下原理图，那颗电容是输入电容，看你输入是多少，耐压值应该不能小于你的输入电压

linkinparkone, 2022-09-16:
> 刷了，卡wifi初始化

请问卡wifi初始化解决了吗？我也遇到了这个问题

Inevitableofcold, 2022-10-09:
问下如果有成品出的话联系我V 13950722089

Inevitableofcold, 2022-10-15:
急收5.5x2.1 至少140W笔记本电源 可以正常给充电站使用的 v 13950722089 可以走咸鱼

djc80s, 2023-03-18:
> https://wwd.lanzout.com/b011rygfa 密码:58r5 这是我在作者基础之上修改的程序，有需要的可以下载 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
看了你仓库开了没放代码，方便分享学习下么。最近正在学习ESP32，按照UP主的配置好后，发现无法编译"'SPI3_HOST' undeclared (first use in this function);"。看到你这有分享，我这就凑上来了。

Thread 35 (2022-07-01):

卡Wi-Fi网络初始化问题

XPY2020, 2022-07-01:
上传程序成功后上电卡在Wi-Fi网络初始化是什么问题
![Uploading 05D3F825-4651-4931-A5AD-9A55078E8ACB.jpeg…]()

XPY2020, 2022-07-01:
![Uploading 23652DD8-1EB5-464C-BA7A-BB810C272022.jpeg…]()

XPY2020, 2022-07-01:
所以up的合并固件上次已经解决了

Closed 2022-07-09.

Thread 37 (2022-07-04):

烧LMBT3904DW1T1G

XiDD93, 2022-07-04:
之前接12v电源没问题，测试完了上19v电源直接LMBT3904DW1T1G着火烧了，换了新的以后接12v电源也一样烧，找了一圈发现SI2309被卖家发错货发成SI2301了，烧LMBT3904DW1T1G会是SI2301的问题吗？

Zyilin98, 2022-07-05:
会

liaozhelin, 2022-07-09:
我的锅，这里上拉电阻应该要改成10K，不过你这着火应该是买错器件了，用1K也就是发热量大

e1585742133, 2022-07-09:
建议拆掉就行了

Closed 2022-07-09.

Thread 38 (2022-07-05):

两个C口均只能输出最高12V

Dustl1ght, 2022-07-05:
我插入我的笔记本电脑只能只能输出12V，无法输出20V，而且需要上电几次才能稳定12V，重新拔插C口数据线有概率会重启设备，我之前已经成功组装了两个了，装第三个的时候出现这个问题了 [https://www.bilibili.com/video/BV1t34y1p72V?share_source=copy_web](url)
@liaozhelin

stig3, 2022-07-05:
你看一下你的输入电源是多少伏的，这个是BUCK型的电源。
另外，看你的描述，感觉是协议没有识别，检查一下焊接呢？

Dustl1ght, 2022-07-05:
> 你看一下你的输入电源是多少伏的，这个是BUCK型的电源。 另外，看你的描述，感觉是协议没有识别，检查一下焊接呢？

 谢谢，电源是24V 6A的，我之前已经焊过两个板子了，都用的挺好，这是第三个，然后就出问题了，而且两个C口都是同样的问题，两个C口的电路都是分开的，按说也不至于两个都这样，会不会是我拿错电容或电阻了

liaozhelin, 2022-07-09:
重点检查焊接以及器件焊接问题

Closed 2022-07-09.

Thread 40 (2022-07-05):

SW3526发热

gzzz2008, 2022-07-05:
SW3526总是发热是怎么回事呢？哪里能短路导致呢？

gzzz2008, 2022-07-05:
好像是IP6525T发热！！我用的是IP6505，这个有影响吗？

gzzz2008, 2022-07-05:
换了IP6525T正常了，但是怎么插电脑没有反应呢？？需要按上上层板子才能插电脑有反应吗？

Zyilin98, 2022-07-05:
不接上层板子 esp32应该是不进bootload模式 电脑应该不认

galamygod, 2022-07-06:
> 好像是IP6525T发热！！我用的是IP6505，这个有影响吗？

不能直接使用6505，他俩脚位不一样的

Closed 2022-07-09.

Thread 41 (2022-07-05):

如何下载程序

gzzz2008, 2022-07-05:
测试电压都是正常的，怎么能下载程序呢？连接电脑一点反应都没有，是不是哪里操作不对呢？能给详细点的教程吗？

ktx888, 2022-07-05:
3.3v供电正常吗

gzzz2008, 2022-07-05:
都是3.2v多，应该算是正常吧。

galamygod, 2022-07-06:
> 都是3.2v多，应该算是正常吧。

我也卡在这步，up说下载驱动，但是我在官网硬是没找到

xiaoqingnian20, 2022-07-07:
先确认芯片是c3fn4的，4行丝印的那种芯片，3行丝印的不带内存，用给的esp32下载工具通过接D+ D- 3.3vvcc gnd  gnd短接gpio9  上电 识别到端口点下载即可

liaozhelin, 2022-07-09:
README中有详解

Closed 2022-07-09.

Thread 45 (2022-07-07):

插上电源屏幕和灯不亮

gzzz2008, 2022-07-07:
用下载口接3.3V的电源可以找到串口下载程序，但是接DC电源不行，但是测量出来的电压都是3.27V，应该差不多吧。但是下载程序后，接上电源屏幕不亮，A口和C口都有电压输出，但是屏幕不亮，灯也不亮，USB接下载口，也没反应，找不到串口。

gzzz2008, 2022-07-08:
ESP32 可以下载进去程序，

liaozhelin, 2022-07-09:
可以下载进去程序屏幕不亮多半是屏幕焊接的问题

Closed 2022-07-09.

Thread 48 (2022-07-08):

烧写程序时电压不正常

fggddfor, 2022-07-08:
从ESP32C3出来的USB D+ 3.3v、USB D- 1v
现在插上电脑，电脑就死机了……

Zyilin98, 2022-07-09:
你看看你是不是焊接有问题 别到时候充电器没做好 把电脑带走了

fggddfor, 2022-07-09:
感谢大佬，是我没接gnd导致的，之前只接了D+ D-，现在再接一根GND电脑就可以识别了

fggddfor, 2022-07-09:
接上GND后电脑不死机了，设备管理器也读出是个usb/jtag设备，但出现一秒就消失，然后一直循环，Windows的自动驱动安装也失败

Zyilin98, 2022-07-09:
应该是不需要驱动也可以  看看是不是3.3V不到位 还是接触问题

fggddfor, 2022-07-09:
![Uploading 7599C77E-91D8-4AEA-8359-905B862CBA10.jpeg…]()
3.3是到位的，现在就是没有驱动

liaozhelin, 2022-07-09:
不断闪现循环是没有进入下载模式的问题，这个在其他issue中也有提及

fggddfor, 2022-07-09:
大佬给个驱动，现在识别到有两个USB JTAG/serial debug unit，但找不到驱动，用项目中的drivers也只能个一个USB JTAG/serial debug unit打上驱动
也看不到串口号

Zyilin98, 2022-07-09:
我都没打驱动你敢信😂 我win11插上就认了 com4

---原始邮件---
发件人: ***@***.***&gt;
发送时间: 2022年7月9日(周六) 下午5:25
收件人: ***@***.***&gt;;
抄送: ***@***.******@***.***&gt;;
主题: Re: [liaozhelin/yds-charger] 烧写程序时电压不正常 (Issue #48)

大佬给个驱动，现在识别到有两个USB JTAG/serial debug unit，但找不到驱动，用项目中的drivers也只能个一个USB JTAG/serial debug unit打上驱动
 也看不到串口号

—
Reply to this email directly, view it on GitHub, or unsubscribe.
You are receiving this because you commented.Message ID: ***@***.***&gt;

fggddfor, 2022-07-10:
感谢大佬，我把win7升到了win10就可以正常识别了

Closed 2022-07-09.

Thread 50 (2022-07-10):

来交作业了

fggddfor, 2022-07-10:
另外，在测试过程中发现18wA口的输出电路发热量普遍较大，输出18w时上散热垫不到10分钟外壳都烫手，特别是IP6525T和LMBT3904DW1T1G
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
l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

mornlena, 2022-07-11:
你焊接是否有问题啊，我的目前最多测试2个a口18瓦，2个c口20瓦，同时，时间30分钟，外壳温度也就40左右，加了散热垫的。

fggddfor, 2022-07-11:
大佬能拍一张下层板的照片吗？我对照着看看

mornlena, 2022-07-12:
拍照片看不出来的，需要你仔细的检查，用维修电源看看输入功率和输出功率对比。你做几套啊，都这样吗？我这里一共做了3套，除了无线信号不太好和那个3d传感器总是无法工作以外，其他都没问题。

fggddfor, 2022-07-12:
做了五套，无线wifi总是收不到信号，转换效率都在67%左右，就很懵

liaozhelin, 2022-07-12:
3904发热问题可以查看其他issue，刚刚也推送了修正后的文件，修改两个上拉电阻即可

mornlena, 2022-07-13:
> 做了五套，无线wifi总是收不到信号，转换效率都在67%左右，就很懵

wifi没信号，你首先把这个放到无线路由器旁边看能不能收到信号，如果还是没有的话，检查晶振和晶振旁边的两颗电容，我的之前是有一个空焊了。67的效率太低了，发热肯定大，检查一下具体是哪里的原因吧。

vicen26, 2022-07-14:
我这边做了3套，都是无法配网，一配网就自动重启，或者没收到，有大佬知道原因吗

vicen26, 2022-07-14:
顺便问下大佬用得是哪个固件

fggddfor, 2022-07-14:
把拨盘向左拨再上电
ESP32只支持2.4G的wifi
固件我用的lssues中open的那个大佬的固件

vicen26, 2022-07-18:
>

我用的是2.4G 的，智能插座那些都能配网，我两个固件都刷过，原版的固件配了几次网没配上，现在进入配网就会自动重启，另一个固件死活配不上

Closed 2022-07-14.

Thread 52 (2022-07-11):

[交流]显示屏保护问题

Zyilin98, 2022-07-11:
我现在加了外壳之后发现 显示屏上端正好跟铝制外壳精准贴合 没啥缝隙 如果摔一下或者磕一下就很有可能把显示屏磕碎
我有想过挪一下显示屏的位置和连接方式 但是板子上空间有限没法转移
就想问问各位大佬们 能不能集思广益 解决一下显示屏的保护问题 至少不会说摔一下 不仅显示屏寄了 主板也可能寄

mornlena, 2022-07-12:
我的是可以正好卡在里面的，你应该可以调整一下，或者你买的屏幕比我们的大一圈，换一种屏幕吧。

Zyilin98, 2022-07-12:
> 我的是可以正好卡在里面的，你应该可以调整一下，或者你买的屏幕比我们的大一圈，换一种屏幕吧。
不是说屏幕压着铝壳 是刚好铝壳和屏幕之间没啥缝隙 精准卡进去

liaozhelin, 2022-07-12:
可以用薄的电工胶布保护下，缝隙的话应该还是有一点排线的空间，但是不多

Zyilin98, 2022-07-12:
> 可以用薄的电工胶布保护下，缝隙的话应该还是有一点排线的空间，但是不多

我试试 昨天晚上本来没想到这个问题 手滑摔了才想起来这个问题 然后给屏幕包了点透明胶 但是还是没什么效果 我试试电工胶带吧

Closed 2022-07-13.

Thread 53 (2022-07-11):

未识别的USB设备 && 晶振方向问题

TheRealKamisama, 2022-07-11:
在刷写固件的过程中接上电脑发现弹窗: 未识别的USB设备
翻阅issue得知可能跟晶振方向有关, 我这里晶振方向见照片
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
(图中Q4错位了, 下次上热台返工)
按照 #21 提出的方法我测了一下, 目前晶振的左上和右下是导通的, 我想请教一下这个方向正确吗?
如果晶振方向正确, 目前还有什么排查的思路?

mornlena, 2022-07-12:
晶振靠近芯片和天线的那个脚是1脚，天线也反了啊啊。

QQ5547155, 2022-07-12:
个人也出现插U口电脑不识别的情况，而且是反复弹窗，开始以为是晶振的问题，我买的晶振比较小，但检查没有问题，仔细看大佬的文字内容和图纸，后来发现一个是需要插电之前把编码开关转至PCB板日期的方向，但还是不行，再检查发现USB线序错误，把U+和U-换个方向，再把编码开关拨一边上电，就都正常了。如有出现类似问题的，仅做参考！感谢大佬开源！！

fggddfor, 2022-07-12:
天线没有方向吧，我也是点在左边，有信号连上后强度不弱但有些时候就连不上

mornlena, 2022-07-13:
红点是1脚，1脚靠近芯片，电路图是这么画的。否则没必要特别标注啊，就好比mlcc电容或者电阻，从来不标正负极

xiaoqingnian20, 2022-07-13:
晶振不需要关心方向，换D+ D- 左拨进刷机模式即可

Closed 2022-07-14.

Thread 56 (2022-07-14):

应该是R27和R28电阻换为10k，不是R29和R30，R27和R28为1K的话还是很烫

galamygod, 2022-07-14:

xiaoqingnian20, 2022-07-17:
检查Q3 Q2是否短路，短路的r27 r29就烫

xiaoqingnian20, 2022-07-17:
还有3904是否短路 也可以把r27 r28都换10k再看

fggddfor, 2022-07-17:
不是3904发热，是2309发热

galamygod, 2022-07-17:
> 不是3904发热，是2309发热

我的3904烧掉以后我就把27  28换为10K，嘛事儿没有了，我按照up说的换29 30，插笔记本电源还是很烫，倒不至于直接烧

mornlena, 2022-07-18:
电源输入电压24v以上时，必烧si2309，造成gs短路，此时输入电压直接加载在3904两端，造成对地短路，3904也会烧毁，如果直接断开，那不会发热，如果不断，那就会发热

Closed 2022-08-12.

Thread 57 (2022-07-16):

上电c2显示的电压0-5v乱跳,且无法进入系统设置

XADZ139, 2022-07-16:
大佬你好
上电c2显示的电压0-5v乱跳,左下方有个充电标志在闪，而且按开关进入不了系统设置，求解
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

程序是这个
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

galamygod, 2022-07-17:
可以试试风枪加焊U1，我的有一个也这样，加焊以后好了，或者你看看C口是不是连锡了

xiyuxixi, 2022-08-05:
C 口没有设备的情况下默认是0V或者0.0几V。你都显示5V了，检查CC线路C口和芯片是否焊接正常。

Closed 2022-08-31.

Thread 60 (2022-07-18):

为什么卡固件更新啊

524322406, 2022-07-18:
如题。请耐心等待。。。连上路由器后跟路由器的ip不是一样的，例如路由器上显示该ip是192.168.0.103，充电器上显示的ip是56.54.51.50

524322406, 2022-07-19:
> 终于看到跟我一样的了，ip显示不对，我的只有最后一位是正确的。

我刷了楼下大佬的固件，正常了，并且成功更新

blacksr, 2022-08-11:
问题如果处理好了的话请麻烦关闭一下Issues噢

Closed 2022-08-11.

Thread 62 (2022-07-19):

无线充电

sinary-sys, 2022-07-19:
有加入无线充电的想法吗，毕竟目前的手机，基本都支持无线充电

galamygod, 2022-07-21:
> 有加入无线充电的想法吗，毕竟目前的手机，基本都支持无线充电

我直接在上层塞了一块20w的小板，固定好以后再贴电胶布，然后上壳挖两个孔把线圈的引脚放进去，无线充电的小板直接飞线接到dc供电座，代价就是有点丑而且电源只能用12V的，不过放办公室用也是完全够了

Closed 2022-08-31.

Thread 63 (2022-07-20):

RY8411 输出4.3V几的电压，问下大概是哪里的问题？

Krnus, 2022-07-20:
RY8411 测出来的都是4.37v的电压🤨

galamygod, 2022-07-21:
四条线，红色供电不接就行了呗，DC插头插上，电脑检测到端口就可以烧录了

Krnus, 2022-07-21:
> 四条线，红色电源不接就行了呗，DC插头插上，电脑检测到端口就可以烧录了

GND D+ D-  直接插电脑检测不到

galamygod, 2022-07-21:
> > 四条线，红色电源不接就行了呗，DC插头插上，电脑检测到端口就可以烧录了
>
> GND D+ D- 直接插电脑检测不到

DC供电啦，万用表打一下3.3V有没有出

SuperPrintf, 2022-07-21:
你找一个USB-A公口，然后把线引出来就行了，GND、D+、D-，VCC连接一个LDO再出来就好

xiaoxinabc, 2022-07-22:
我也不能识别 接了DC.  3.3v也有了 用的usb线连接的三个下载GND、D+、D-  识别不到
是不是没有取东西啊
弄了好久了

SuperPrintf, 2022-07-22:
> 我也不能识别 接了DC. 3.3v也有了 用的usb线连接的三个下载GND、D+、D- 识别不到
> 是不是没有驱动呀
> 弄了好久了

你是不是没共地？

galamygod, 2022-07-22:
>
不仅仅是烧录脚的3.3，还要看e主控有没有电压，你测一下c15是不是3v左右

galamygod, 2022-07-22:
> 我也不能识别接了 DC。3.3v也有用的usb线连接的三个下载GND、D+、D- 不知 是不是没有驱动呀 弄了好久了

你看一下c15有没有电压，看看主控有没有通电

galamygod, 2022-07-22:
> 我也不能识别接了 DC。3.3v也有用的usb线连接的三个下载GND、D+、D- 不知 是不是没有驱动呀 弄了好久了

电脑是win10的话都不用安装驱动的

xiaoxinabc, 2022-07-22:
是win10可能还是硬件没弄好

xiaoxinabc, 2022-07-22:
刚刚量了 c15 有电压，但是从3v一直在往下降

galamygod, 2022-07-22:
> 刚刚量了 c15 有电压，但是从3v一直在往下降

加焊一下主控试试，或者换一片

xiaoxinabc, 2022-07-22:
今天下班 重新焊接 现在还是不行 崩溃

blacksr, 2022-08-11:
> 今天下班 重新焊接 现在还是不行 蓝瘦啊

识别不到的话大概率是32芯片没有焊接好，你是用什么焊接的呢，QFN封装风枪还是挺容易虚焊的，建议用烙铁加焊一遍
识别不到可以按照下面步骤排查一下问题
1、如果使用的是DC供电在连接电脑前测量烧录口四个脚的正负有没有3.3V
2、如果3.3没问题的话插上电脑设备管理器是否有反应（新设备接入）
3、没有反应的话大概率是32芯片虚焊
4、有反应的话恭喜你烧录口到32芯片的硬件焊接是没有问题的，这时候需要将上板接上开关往左拨再上电进入bootmode
5、如果设备是识别到然后又不见了，类似一直插拔的效果的话同样开关左拨进入bootmode就正常了
6、查看电脑是否识别出一个串口或未知设备，有串口就不需要安装驱动，有新的未知设备接入就需要将这个未知设备装上驱动，驱动文件在仓库里面的，驱动正常后会有一个串口号，然后就可以进行烧录的动作了

Closed 2022-08-31.

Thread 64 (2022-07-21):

大佬你好，请问能否出一个顶层无电容钻孔的版本？

SuperPrintf, 2022-07-21:
我在尝试全部使用固态电容，全部使用了 8*8规格的电容，它们的高度刚好在层间可容纳的范围之内，所以我在考虑能否将顶部板的电容孔去掉。但是拿到的是Gerber制板文件没办法进行修改，想请问一下大佬能否再出一款没有电容钻孔的版本。
这是我的成品图
[图1].https://tva1.sinaimg.cn/large/e6c9d24ely1h4eom4c5hcj21400u0n3b.jpg
[图2].https://tva1.sinaimg.cn/large/e6c9d24ely1h4eokp7fq3j21400u0n3n.jpg
可以看到电容的高度是可以控制在上层板之下的（上层板的位置刚好在两颗CDRH127NP的最高处），所以上下层之间的空间是完全可以容纳下电容的

galamygod, 2022-07-21:
我靠，8*8在哪买的，能给个链接吗

SuperPrintf, 2022-07-21:
> 我靠，8*8在哪买的，能给个链接吗

35V100uF:https://m.tb.cn/h.fxuesfN?tk=pj2M2JICx1R CZ3457
16V470uF:https://m.tb.cn/h.fyHj4dF?tk=eoGj2JIyKuQ CZ0001
35V220uF:https://m.tb.cn/h.fDDYrzx?tk=EFLq2JIym8C CZ3457

liaozhelin, 2022-08-31:
可以发邮箱给我，我发你源文件

Closed 2022-08-31.

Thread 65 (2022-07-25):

[Warn]某些设备不支持快充可能需要关闭PPS

Zyilin98, 2022-07-25:
最近从多个渠道观察到 某些设备在使用一些别的充电器的时候 能正常的进行快充 而到了智融芯片的设备就不能正常快充 症状是只能握手最低5V电压 然后求证过后发现是 PD PPS协议作祟
所以 还请各路大佬能在固件里加个 PD PPS 协议的开关(SW3526的i2s总线应该是能关闭这个的) 防止这些稀有设备 快充问题

#33  这位大佬的固件已经支持关闭PPS快充 如果有小米手机用户充电仅触发5V 可以去试试这位大佬的固件

stig3, 2022-07-27:
SW3526的i2s总线应该是能关闭这个的
------------------------------------------
你这个消息从那里看到的？
我看了规格书还有iic协议，没有关闭这个协议的
iic只能设置功率读取芯片状态。

Zyilin98, 2022-07-27:
> ## SW3526的i2s总线应该是能关闭这个的
> 你这个消息从那里看到的？ 我看了规格书还有iic协议，没有关闭这个协议的 iic只能设置功率读取芯片状态。
https://item.taobao.com/item.htm?spm=a230r.1.14.27.1f9a4f23cJaIgt&id=671728778645&ns=1&abbucket=4#detail
你看这个 同样也是sw3526 在他的固件里就设置了pps协议等等等协议的软件开关 同时他连pcb都发出来了
https://item.taobao.com/item.htm?spm=a1z10.5-c.w4002-5539902433.19.6c1d51dbWXiiB7&id=624481901312
这个是SW3518S 这个我还特意去问了 是通过i2s总线关闭sw3518S的pps快充的

stig3, 2022-07-27:
我看了协议，的确是可以的

操作寄存器A9就可以
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

你可以尝试在
```c
SW35xxWriteReg(SW35XX_PWR_CONF,0x07,SW_I2C_2);//设定功率限制为64W
```
之前增加
```c
SW35xxWriteReg(0xA9,0x3F,SW_I2C_2);//操作0xA9寄存器 关闭前两位PPS设置
SW35xxWriteReg(SW35XX_PWR_CONF,0x07,SW_I2C_2);//设定功率限制为64W
```

你可以试一下，我没有相关设备，没法测试。

Zyilin98, 2022-07-27:
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

刚看见 感谢老哥的代码分享 顺便问一句 这个不会影响20v pd档位的诱骗吧
我有时间修改源码 编译一版试试

Closed 2022-08-31.

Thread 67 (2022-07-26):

请问大佬输入延时+防反接+过流保护模块中的R19阻值和OLED显示模块中的R9阻值分别是多少呢，还有C63和C53的容值分别是多少呢

linkinparkone, 2022-07-26:
这个模块中的R9阻值是多少呢？
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

OLED显示模块中的R9阻值是4.7k吗
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

linkinparkone, 2022-07-26:
C53的容值是多少呢？
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

C63的容值是多少呢

1075081239, 2022-07-26:
我推测R9就是4.7k

linkinparkone, 2022-07-26:
>

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
我在csdn上找到了这个显示屏驱动电路，确实4.7k

1075081239, 2022-07-26:
> C53的容值是多少呢？ 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
>
> C63的容值是多少呢

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
我查阅了RY8411的芯片手册，这个电容应该是Cff
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
由于芯片有内部电路补偿，这个电容可以不加，如果加可以按以上公式计算。

linkinparkone, 2022-07-26:
非常感谢您的回复，不过我不懂这个Fcross（cross frequency）是什么意思。在此图中应该取什么值呢

------------------&nbsp;Original message&nbsp;------------------
From: "destineda";
Sendtime: Tuesday, Jul 26, 2022 9:37 PM
To: "liaozhelin/yds-charger";
Cc: ***@***.***>; "Author";
Subject: Re: [liaozhelin/yds-charger] 请问大佬输入延时+防反接+过流保护模块中的R19阻值和OLED显示模块中的R9阻值分别是多少呢，还有C63和C53的容值分别是多少呢 (Issue #67)

C53的容值是多少呢？

C63的容值是多少呢

 我查阅了RY8411的芯片手册，这个电容应该是Cff

 由于芯片有内部电路补偿，这个电容可以不加，如果加可以按以上公式计算。

—
Reply to this email directly, view it on GitHub, or unsubscribe.
You are receiving this because you authored the thread.Message ID: ***@***.***&gt;

1075081239, 2022-07-26:
emmm这个需要作者分析网络了，我也不知道（无奈doge）

1075081239, 2022-07-26:
问了一下群友，NC应该都不用接

Krnus, 2022-07-26:
> 问群友，NC应该用接

方便拉一下群吗

blacksr, 2022-07-30:
其实那些NC、NA不接都是可以用的，当然我不太清楚你是不是要做什么其他功能

linkinparkone, 2022-07-31:
不做别的功能，只是想复刻这个项目。不接那就省事儿了，谢谢啦

发自我的iPhone

------------------ 原始邮件 ------------------
From: blacksr ***@***.***&gt;
发送时间: 07/31/2022, 02:56
To: liaozhelin/yds-charger ***@***.***&gt;
抄送: lrvin ***@***.***&gt;, Author ***@***.***&gt;
Subject: Re: [liaozhelin/yds-charger] 请问大佬输入延时+防反接+过流保护模块中的R19阻值和OLED显示模块中的R9阻值分别是多少呢，还有C63和C53的容值分别是多少呢 (Issue #67)

其实那些NC、NA不接都是可以用的，当然我不太清楚你是不是要做什么其他功能

—
Reply to this email directly, view it on GitHub, or unsubscribe.
You are receiving this because you authored the thread.Message ID: ***@***.***&gt;

Closed 2022-08-31.

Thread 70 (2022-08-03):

问下电压电流异常充电站会这么显示，发出什么样的报警？

Inevitableofcold, 2022-08-03:

Inevitableofcold, 2022-08-03:
问下电压电流异常充电站会怎么显示，发出什么样的报警？

ktx888, 2022-08-03:
设置->系统监控->异常代码

ktx888, 2022-08-03:
uint8_t event = u8x8_GetMenuEvent(u8g2_GetU8x8(&u8g2));
    u8g2_ClearBuffer(&u8g2);
    u8g2_DrawUTF8(&u8g2, 0, 15, "C1异常代码");
    u8g2_DrawUTF8(&u8g2, 20, 31, "系统无故障");
    if (sw35xx_c1.state.val_input_upmax)
      u8g2_DrawUTF8(&u8g2, 20, 31, "输入电压过高！");
    if (sw35xx_c1.state.tem_alarm_upmax)
      u8g2_DrawUTF8(&u8g2, 20, 31, "芯片温度过高！");
    if (sw35xx_c1.state.tem_shutdown)
      u8g2_DrawUTF8(&u8g2, 20, 31, "高温关机保护！");
    if (sw35xx_c1.state.short_citcuit)
      u8g2_DrawUTF8(&u8g2, 20, 31, "输出短路！"); // 0x05版本的芯片貌似不能用
    u8g2_DrawUTF8(&u8g2, 0, 47, "C2异常代码");
    u8g2_DrawUTF8(&u8g2, 20, 63, "系统无故障");
    if (sw35xx_c2.state.val_input_upmax)
      u8g2_DrawUTF8(&u8g2, 20, 63, "输入电压过高！");
    if (sw35xx_c2.state.tem_alarm_upmax)
      u8g2_DrawUTF8(&u8g2, 20, 63, "芯片温度过高！");
    if (sw35xx_c2.state.tem_shutdown)
      u8g2_DrawUTF8(&u8g2, 20, 63, "高温关机保护！");
    if (sw35xx_c2.state.short_citcuit)
      u8g2_DrawUTF8(&u8g2, 20, 63, "输出短路！"); // 0x05版本的芯片貌似不能用

Inevitableofcold, 2022-08-03:
感谢回复

------------------&nbsp;原始邮件&nbsp;------------------
发件人:                                                                                                                        "liaozhelin/yds-charger"                                                                                    ***@***.***&gt;;
发送时间:&nbsp;2022年8月3日(星期三) 晚上9:52
***@***.***&gt;;
***@***.***&gt;;"State ***@***.***&gt;;
主题:&nbsp;Re: [liaozhelin/yds-charger] 问下电压电流异常充电站会这么显示，发出什么样的报警？ (Issue #70)

uint8_t event = u8x8_GetMenuEvent(u8g2_GetU8x8(&amp;u8g2));
 u8g2_ClearBuffer(&amp;u8g2);
 u8g2_DrawUTF8(&amp;u8g2, 0, 15, "C1异常代码");
 u8g2_DrawUTF8(&amp;u8g2, 20, 31, "系统无故障");
 if (sw35xx_c1.state.val_input_upmax)
 u8g2_DrawUTF8(&amp;u8g2, 20, 31, "输入电压过高！");
 if (sw35xx_c1.state.tem_alarm_upmax)
 u8g2_DrawUTF8(&amp;u8g2, 20, 31, "芯片温度过高！");
 if (sw35xx_c1.state.tem_shutdown)
 u8g2_DrawUTF8(&amp;u8g2, 20, 31, "高温关机保护！");
 if (sw35xx_c1.state.short_citcuit)
 u8g2_DrawUTF8(&amp;u8g2, 20, 31, "输出短路！"); // 0x05版本的芯片貌似不能用
 u8g2_DrawUTF8(&amp;u8g2, 0, 47, "C2异常代码");
 u8g2_DrawUTF8(&amp;u8g2, 20, 63, "系统无故障");
 if (sw35xx_c2.state.val_input_upmax)
 u8g2_DrawUTF8(&amp;u8g2, 20, 63, "输入电压过高！");
 if (sw35xx_c2.state.tem_alarm_upmax)
 u8g2_DrawUTF8(&amp;u8g2, 20, 63, "芯片温度过高！");
 if (sw35xx_c2.state.tem_shutdown)
 u8g2_DrawUTF8(&amp;u8g2, 20, 63, "高温关机保护！");
 if (sw35xx_c2.state.short_citcuit)
 u8g2_DrawUTF8(&amp;u8g2, 20, 63, "输出短路！"); // 0x05版本的芯片貌似不能用

—
Reply to this email directly, view it on GitHub, or unsubscribe.
You are receiving this because you modified the open/close state.Message ID: ***@***.***&gt;

Closed 2022-08-31.

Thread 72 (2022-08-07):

RGB灯和屏幕都点不亮 求大佬看看

1075081239, 2022-08-07:
刷写固件后两个A口可以正常充电，但是RGB灯和屏幕都不亮，请问可能是什么原因

blacksr, 2022-08-11:
C口能正常输出吗，先确认32是不是正常跑起来了，（程序如果烧进去的话应该是跑起来了）
屏幕的话电容如果上错了是没法点亮的，检查一下原理图和实际上的料，对着原理图打一下屏幕排线那边的电压是不是正常的；
RGB灯应该好解，量一下4脚有没有3.3，3脚到32芯片的9脚是不是通的就行；
你这里都是到32芯片的问题，估计是32没焊接好，后面A口不需要32芯片也能工作，如果C口没有输出的话加焊一下32芯片试试

Closed 2022-08-31.

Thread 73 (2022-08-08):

电脑找不到芯片，是没装驱动吗？

Zhangyucong0210, 2022-08-08:
希望大佬能提供一下驱动

1075081239, 2022-08-09:
这个需要将拨码开关左拨（作者readme中的方向）再上电，进入BOOT模式，可以看到串口com*，这个应该不需要驱动的

blacksr, 2022-08-11:
电脑设备管理器有识别到东西吗，任意都可以，如果没有的话建议检查一下最小系统里的焊接和原件是否上错，另外建议把32芯片加焊一下，风枪吹QFN封装还是很容易虚焊的

Zhangyucong0210, 2022-08-12:
大佬们能提供一下项目里分立下载的bin文件吗，没找到独立的bin文件，我驯化ESPIDF失败了，合并下载的bin文件好像功能很少。只有个气象站？

blacksr, 2022-08-12:
- #33
这个issue里分享的固件功能比较多更新的也比较勤，OTA功能也有

Els1314, 2022-08-28:
拨码通电后只有串口多了2个JTAG，端口COM没有反应，是什么回事？

blacksr, 2022-08-28:
> 拨码通电后只有串口多了2个JTAG，端口COM没有反应，是什么回事？

有图片吗，设备管理器截个图看一下可能需要安装驱动

Els1314, 2022-08-28:
拨码通电后只有串口多了2个JTAG，端口COM没有反应，是什么回事？

liaozhelin, 2022-08-31:
能检测到jtag应该问题不大，大概率还是驱动问题

a1659746547, 2022-09-05:
> 电脑设备管理器有识别到东西吗，任意都可以，如果没有的话建议检查一下最小系统里的焊接和原件是否上错，另外建议把32芯片加焊一下，风枪吹QFN封装还是很容易虚焊的
>
> Computer Device Manager recognize anything? If not, it is recommended to check the minimum system welding and the original is wrong, and it is recommended to add the 32 chip welding, air Gun blowing QFN package is easy to solder

接入后在com有提示未知设备是正常的吗。晶振电容我使用20pf代替有无影响的？求解答

a1659746547, 2022-09-05:
> 电脑设备管理器有识别到东西吗，任意都可以，如果没有的话建议检查一下最小系统里的焊接和原件是否上错，另外建议把32芯片加焊一下，风枪吹QFN封装还是很容易虚焊的

接入后在com有提示未知设备是正常的吗。晶振电容我使用20pf代替有无影响的？求解答

a1659746547, 2022-09-05:
> > 电脑设备管理器有识别到东西吗，任意都可以，如果没有的话建议检查一下最小系统里的焊接和原件是否上错，另外建议把32芯片加焊一下，风枪吹QFN封装还是很容易虚焊的
>
> 接入后在com有提示未知设备是正常的吗。晶振电容我使用20pf代替有无影响的？求解答
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

a1659746547, 2022-09-05:
> 这个需要将拨码开关左拨（作者readme中的方向）再上电，进入BOOT模式，可以看到串口com*，这个应该不需要驱动的

这个是必须的嘛

blacksr, 2022-09-05:
> > 这个需要将拨码开关左拨（作者readme中的方向）再上电，进入BOOT模式，可以看到串口com*，这个应该不需要驱动的
>
> 这个是必须的嘛

对的 进入bootmode是必须将拨码开关左拨然后再上电的

> > 电脑设备管理器有识别到东西吗，任意都可以，如果没有的话建议检查一下最小系统里的焊接和原件是否上错，另外建议把32芯片加焊一下，风枪吹QFN封装还是很容易虚焊的
>
> 接入后在com有提示未知设备是正常的吗。晶振电容我使用20pf代替有无影响的？求解答

电路原理我不是很懂，所以电容不一样我不清楚；
如果有显示未知设备的话可以试着装一下驱动先，驱动文件在仓库里是有的；

shileinuo, 2022-10-20:
库里的驱动不支持win10啊，还有没其它链接我也装不上驱动，识别不到com

Zhangyucong0210, 2022-10-20:
可能是焊接有问题
&nbsp;

张聿璁
***@***.***

&nbsp;

------------------&nbsp;原始邮件&nbsp;------------------
发件人: ***@***.***&gt;;
发送时间: 2022年10月20日(星期四) 下午3:38
收件人: ***@***.***&gt;;
抄送: ***@***.***&gt;; ***@***.***&gt;;
主题: Re: [liaozhelin/yds-charger] 电脑找不到芯片，是没装驱动吗？ (Issue #73)

库里的驱动不支持win10啊，还有没其它链接我也装不上驱动，识别不到com

—
Reply to this email directly, view it on GitHub, or unsubscribe.
You are receiving this because you authored the thread.Message ID: ***@***.***&gt;

blacksr, 2022-10-20:
> 库里的驱动不支持win10啊，还有没其它链接我也装不上驱动，识别不到com

有识别出东西嘛，识别到了才能装驱动，你是怎么安装的驱动呢

shileinuo, 2022-10-20:
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

shileinuo, 2022-10-20:
拨盘上电识别出未知USB设备，装了两块板子都这样

blacksr, 2022-10-20:
> 拨盘上电识别出未知USB设备，装了两块板子都这样

右键选inf文件进行安装装不上吗

shileinuo, 2022-10-20:
选inf 文件安装提示不是为X64系统兼容的

shileinuo, 2022-10-20:
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

blacksr, 2022-10-20:
> 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

你电脑系统不是64位的吗

shileinuo, 2022-10-20:
就是win10 64位专业版啊 所以安装不上奇怪啊，用的是作者固件压缩包里的驱动。。

shileinuo, 2022-10-20:
或者你发一份驱动我试试呗 183445831@qq.com  感谢

shileinuo, 2022-10-26:
永远找到原因了，奶奶个熊！买的是无源40m晶振发来是有源的！没仔细看。。。。

Closed 2022-08-31.

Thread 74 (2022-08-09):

请问采购原件是以bom为准吗？

NereeScarlet, 2022-08-09:
采购指南里面的图片和bom里面的参数似乎有一些对不上的地方，然后位号似乎也有对不上的地方（在下是个真小白，如果是有什么不清楚的地方说错了还请原谅QAQ）
像是C1,C4,C44,C61,C65这几个看bom里面都是一种类型的原件，然而采购指南里面c1、c44是一种用的是那个直插固态电容， C59,C60,C4,C65,C61 又是另外一种，用的是那个高频低阻直插铝电解电容。
就是那个……到底是以哪个为准啊QAQ求求大佬救救孩子吧，再有不到俩月在下妹妹生日就到了，QAQ

shui136, 2022-08-09:
可以按照github仓库中 hardware/采购指南.md 的购买
https://github.com/liaozhelin/yds-charger/blob/main/1.Hardware/%E5%99%A8%E4%BB%B6%E9%87%87%E8%B4%AD%E6%8C%87%E5%8D%97.md

NereeScarlet, 2022-08-11:
但是问题是bom现在似乎和采购指南出现了一些不同之处啊……

blacksr, 2022-08-11:
#64
几个插件电容可以参考这个Issue

其实没有要求一定要买什么样的，实在不行就全上固态电容就行；
其他的电容没标的买50V的就肯定没错，标了电压的就按照电压买就行，精度有钱就上好的没有就1% 5%的都可以，有一些非标电阻买不到的话我买的近似阻值容值都是能够正常工作的，直接立创一站配齐就行，一些特殊料或者比较贵（比如屏幕）的料就去淘宝买；
关于屏幕购买注意不要买错了，我就是买错了，淘宝上有两家店，卖的同样的型号，尺寸却不一样，详见这个issue：
#39
#26
这两篇issue里面有讨论屏幕尺寸问题的

NereeScarlet, 2022-08-11:
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

非常感谢！！！

Closed 2022-08-31.

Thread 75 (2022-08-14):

板子发生了一件很离谱的事，求解决

1075081239, 2022-08-14:
焊接好后接5V电压，RY8411一直输出0.97V左右，找了很久没找到原因，接上12V后冒出了一点点黑烟，然后就正常输出3.3V了，再接上5V也是正常输出3.3V，求大佬看看什么原因，附上板子照片如下
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

mornlena, 2022-08-24:
肯定之前3.3v输出后面有短路啊，烧掉了短路，就正常了，查找焊接吧

liaozhelin, 2022-08-31:
是的，应该是某些地方短路了

Closed 2022-08-31.

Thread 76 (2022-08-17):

请问BOM表中的贴片阻容器件选型，电压功率要求，电容16V，电阻0.1W是否够用

yrjaycn, 2022-08-17:
由于专业知识限制，无力分析电路图中各点位的电压电流，特咨询
BOM表中除少量特别标注了型号的物料，在选型时遇到困扰
电容物料：除少量有标注电压的，其他物料用16V规格的贴片电容是否够用。
电阻物料：BOM表中没有标注功率要求，看0.1W的物料最通用，请问0.1W的功率规格是否够用，是否有需要提高规格的点位
以上咨询，感谢回复
tks

liaozhelin, 2022-08-31:
除了采样电阻，其他功率无所谓，主线上的贴片电容用35v的比较好

Closed 2022-08-31.

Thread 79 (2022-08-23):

两个C口均显示0.00V 0.00A

wd5457, 2022-08-23:
最初的问题是两个A口正常，C1口正常，C2口空载显示5V且无法快充，拨轮开关无效。
重新焊接SW3526后两个C口都显示0.00V 0.00A且无法工作，应该不是SW3526焊接的问题，更换了新的并重新焊接了几次都是这样，还可能有什么原因呢？

mornlena, 2022-08-24:
电压，电流是通过i2c总线读取数据的，空载的情况，电压应该有个0.03左右的底数，没有的话就说明sw3526和esp32主芯片之间的通讯有问题，焊接是一方面， 芯片损坏也是有可能的！具体到无法快充，要检查c口的cc1，cc2 和dp这几条线和sw3526的连接，也涉及到焊接问题，仔细检查吧，电路没问题，很多人验证过了！

liaozhelin, 2022-08-31:
是的，跟着上面大佬们说的做就可以

Closed 2022-08-30.

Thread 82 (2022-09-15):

制板问题

gchdfh1, 2022-09-15:
请问github仓库里的主板制板文件哪个是最新的？因为我看到好几个一样的文件只是命名不同

blacksr, 2022-09-16:
制版文件一共有四份，嘉立创打板的话传Gerber就行了

·TopBoard
这个是上板，用于拓展第二个C口输出和拨码开关，里面有两份Gerber文件，topBoard-Fix是重新布线的4层板，topBoard是旧的两层板，两个都可以用，部分地区嘉立创下单两层板工艺做不了的可以下4层板的订单就可以正常下单

·BottomBoard
这个是下板，是整个项目的核心部分，所有的功能都集成在这块下板上

·Back/FrontBoard
这个是前后的挡板，没有任何电路，只做固定和装饰作用，如果想自己制作外壳的话这两块板可以不打，如果是完全复刻项目的话就打这两块板

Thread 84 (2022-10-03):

可以提出硬件功能的建议吗

guougopeng, 2022-10-03:
非常喜欢UP主这个四路独立芯片的设计，这几乎正是我需要的充电器。但是还是希望UP主能在未来的改进中提供一个100W的C口方便给笔记本供电，如果这个C口能提供升压功能就更好了，方便12V供电。虽然现在电路板元件已经很密集了，但还是希望UP主能够考虑我提出的建议。谢谢啦

Zyilin98, 2022-10-04:
升压是真的没地方做了 100W的chip可能需要外置mos 电感大小也会更大 可能当前的外壳放不下

Foxzc, 2022-10-10:
PD支持100W就完美了

Inevitableofcold, 2022-10-15:
急收5.5x2.1 至少140W笔记本电源 可以正常给充电站使用的 v 13950722089 可以走咸鱼

Closed 2022-10-29.

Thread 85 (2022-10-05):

刷入固件后，充电功能正常但是OLED和LED不亮

yrjaycn, 2022-10-05:
想要请教，目前固件已经显示刷入完成
刷入固件后，测试已经具备充电功能，但是OLED显示屏和充电指示灯都不亮
想要请教是需要检查哪里呢。

Zyilin98, 2022-10-06:
看看你esp是不是没有工作 顺便量一下C15 这个电容的两端电压 看看是不是3.3V

Zyilin98, 2022-10-07:
> > 看看你esp是不是没有工作 顺便量一下C15 这个电容的两端电压 看看是不是3.3V
>
> 你好，感谢回复 输入DC12V，量测C15两端有3.26V电压，还在允差范围内，姑且认为有3.3V了 空载量测晶振信号脚有0.81V电压，OLED部分脚和LED电源脚有电压。不专业的判断应该ESP是有在工作的但是屏幕和LED均未能亮起。

你试试重新刷写固件 或者换个新的esp32？

yrjaycn, 2022-10-09:
> 你试试重新刷写固件 或者换个新的esp32？

重新刷过固件了，没有变化，还刷过Issue中的那个固件都不行
主要是做了3个，总不能3个esp32都是统一坏的 -_-||

Zyilin98, 2022-10-09:
> > 你试试重新刷写固件 或者换个新的esp32？
>
> 重新刷过固件了，没有变化，还刷过Issue中的那个固件都不行 主要是做了3个，总不能3个esp32都是统一坏的 -_-||

考虑是不是你买错esp了 这个是需要内置rom的esp

yrjaycn, 2022-10-21:
> 考虑是不是你买错esp了 这个是需要内置rom的esp 具体型号是ESP32C3-FN4

确认没有买错，猜测应该是我焊接等硬件上的问题

csdf, 2022-10-22:
烧录完成后可以用esp idf自带的monitor观察下调试输出，看看是哪里的问题

csdf, 2022-10-22:
> > 考虑是不是你买错esp了 这个是需要内置rom的esp 具体型号是ESP32C3-FN4
>
> 确认没有买错，猜测应该是我焊接等硬件上的问题

烧录完成后可以用esp idf自带的monitor观察下调试输出，看看是哪里的问题

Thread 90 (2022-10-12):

不能快充联想小新笔记本

guougopeng, 2022-10-12:
用这个充电器的C口给联想小新笔记本充电发现可以识别协议为PD FIX，但是充电电流在0A到2点几A间反复横跳，最终充电很慢。用360的65W氮化镓就能稳定在2.6A左右充电。请问应该从那个方向去找这个故障的原因？

guougopeng, 2022-10-12:
研究了下可能是触发了3526过流保护。在电池很空时，电流跳的厉害，电池快充满功率小了，反而能维持40多W的功率。等C口功率限制功能上线了试试看，外部限制防止过流，会不会就稳定了。

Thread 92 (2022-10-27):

三极管发热疑问

yrjaycn, 2022-10-27:
在使用中发现，设备的Q2、Q3、Q4，在挂上负载的时候发热严重
尤其Q2、Q3，对对应A口高电流负载（5V3A）时，热成像仪显示温度超过三百度。
降低负载至1A时，热成像显示温度下降至约100°C，猜测是有大电流通过三极管，由于本身压降关系导致严重发热。
通过原理图，发现三极管并不直接处理充电过程，是用作MCU对充电口的某种管理功能
那么如果想解决发热问题，是否可以直接移除这3个三极管，以牺牲掉MCU对充电口的控制，来达到降低发热的目的呢？

Zyilin98, 2022-10-29:
当然可以 主要是mcu对充电口控制功能还没做
将Q2 Q3 位置进行一坨锡短接 并且移除Q4这个双三极管和它两侧的10K/1K电阻就可以了

yrjaycn, 2022-10-29:
> 当然可以 主要是mcu对充电口控制功能还没做 将Q2 Q3 位置进行一坨锡短接 并且移除Q4这个双三极管和它两侧的10K/1K电阻就可以了

感谢回复
根据回复查了下原理图，那就是移除Q2、Q3、Q4、R27、R28、R29、R30这3个三极管和4个电阻，用途就是切断了MCU对两个A口的控制，同时Q2和Q3的VBUS PAD和VIN PAD需要短接起来，不然A口就断电了。

Zyilin98, 2022-10-29:
> > 当然可以 主要是mcu对充电口控制功能还没做 将Q2 Q3 位置进行一坨锡短接 并且移除Q4这个双三极管和它两侧的10K/1K电阻就可以了
>
> 感谢回复 根据回复查了下原理图，那就是移除Q2、Q3、Q4、R27、R28、R29、R30这3个三极管和4个电阻，用途就是切断了MCU对两个A口的控制，同时Q2和Q3的VBUS PAD和VIN PAD需要短接起来，不然A口就断电了。

对的 就是这样 主要是这些三极管质量参差不齐 可能作者做方案的时候没啥问题 到咱们手里实现可能多少有点问题

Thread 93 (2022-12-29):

关于开发环境搭建

a1659746547, 2022-12-29:
配置在vs code中配置ESPRESSIF中遇到无法访问端口，网络已经设置过代理了，无论github还是国内源都无法正常配置，有哪个大佬遇到过吗。
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

mornlena, 2022-12-31:
https://dl.espressif.cn/dl/esp-idf/?idf=4.4 去这里下载4.4的离线安装包，安装到电脑，记住安装路径，然后在你现在的这个界面选择 本地 下面设置好你安装的目录，就行。

mornlena, 2022-12-31:
https://dl.espressif.cn/dl/esp-idf/?idf=4.4 去这里下载4.4的离线安装包，安装到电脑，记住安装路径，然后在你现在的这个界面选择 本地 下面设置好你安装的目录，就行。

a1659746547, 2023-01-01:
> https://dl.espressif.cn/dl/esp-idf/?idf=4.4 去这里下载4.4的离线安装包，安装到电脑，记住安装路径，然后在你现在的这个界面选择 本地 下面设置好你安装的目录，就行。

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
提示无效，求答疑

mornlena, 2023-01-01:
D:\Espressif\frameworks\esp-idf-v4.4.3，我的是这个，你参考，tools，是D:\Espressif

a1659746547, 2023-01-03:
> D:\Espressif\frameworks\esp-idf-v4.4.3，我的是这个，你参考，tools，是D:\Espressif

问题已解决，非常感谢！！！

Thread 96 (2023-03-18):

编译问题

djc80s, 2023-03-18:
按照博主教程一路顺畅直到编译博主的工程的时候出现错误：'SPI3_HOST' undeclared (first use in this function);
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
尝试切换IDF版本：
release/4.4,
v4.4.4
v5.0.1
都是一样，看了原理图用的标签是I2C接口我就更不懂了，所以这里我是配置问题？还是代码有微调,我搞不定。

djc80s, 2023-03-18:
查了下资料，发现C3无SPI3，这里用到的为I2C，所以这里先改为SPI1编译通过即可(实际中没有用到这部分代码)。

Closed 2023-03-18.

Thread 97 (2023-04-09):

拨钮 WiFi问题请教

xuanyuanss, 2023-04-09:
小白请教大佬，可能问题比较多
刷大佬原始固件，开机后拨钮没用，连续按几次屏幕会卡死，刷固件时拨动开关后可以连电脑
刷ktx888大佬的固件，显示走到请使用esptouch，但是搜不到热点
实际充电时可以的，给iPhone12 充电可以达到11w
小白一个，没有电子基础，但是又手贱，就想玩，请大佬们赐教

xuanyuanss, 2023-04-10:
目前给iPhone12 充电只能达到11w，协议pd fix，其他问题已解决

Closed 2023-06-28.

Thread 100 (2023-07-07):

上层板有2个电容没打孔，Gerber_topBoard-Fix与Gerber_topBoard都是

kialison, 2023-07-07:
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
请问是现在wen'jian文件的问题还是什么原因？

aigaokeji, 2023-12-01:
有没有做好的pcd文件

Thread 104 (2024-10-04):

固件分享

Zyilin98, 2024-10-04:
接手了[ktx888/yds_charger](https://github.com/ktx888/yds_charger) 的固件源码，开始维护新的功能。
这是新的[项目地址](https://github.com/Zyilin98/yds_charger)

liaozhelin, 2024-11-27:
谢谢Zyilin98，工作太忙没精力维护，真心感谢各位大佬们~

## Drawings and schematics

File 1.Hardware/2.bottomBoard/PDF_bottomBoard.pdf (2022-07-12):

128 x 64

# GND¹⁰⁵ C³

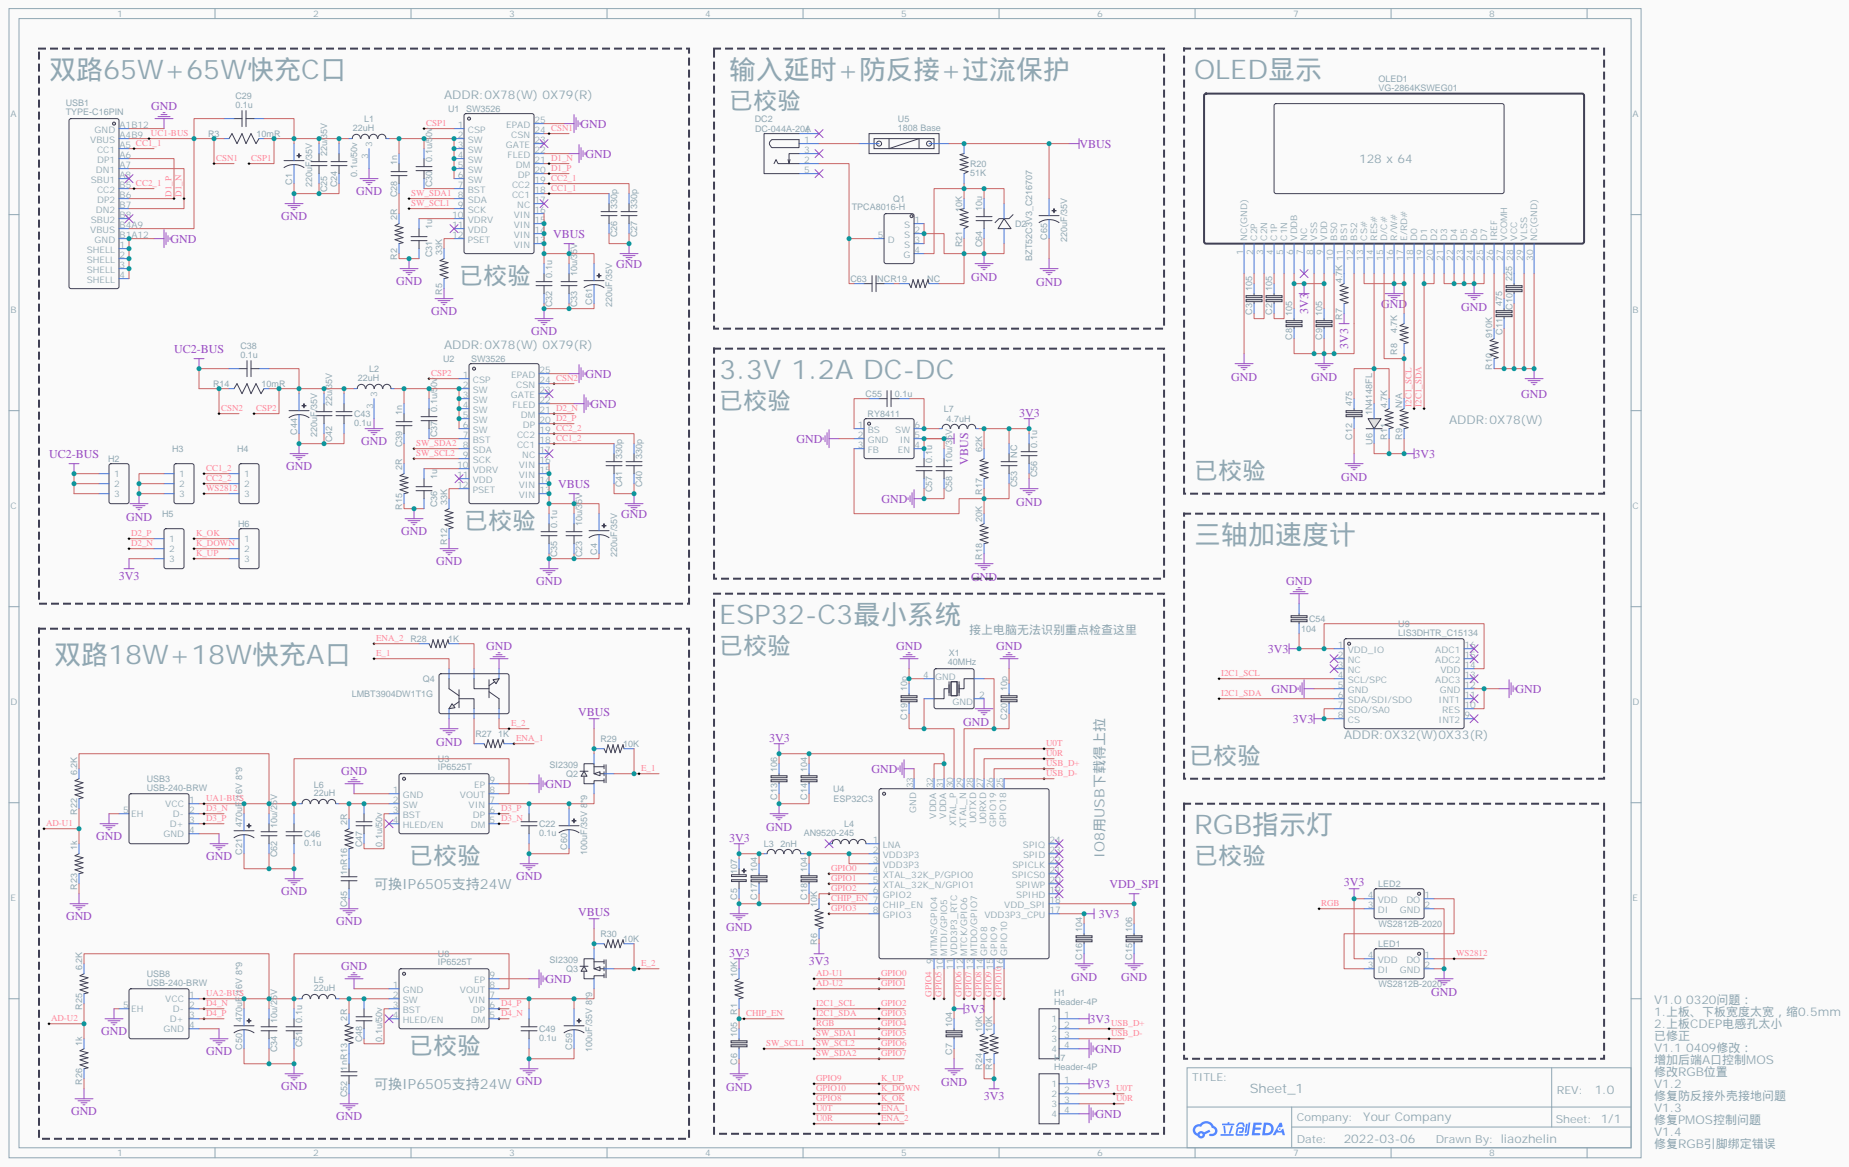
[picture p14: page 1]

ADDR:0X78(W) 0X79(R)
VIN 13 VIN 14 VIN 15 VIN 16 NC 17 CC1 18 CC2 19 DP 20 DM 21 FLED 22 GATE 23 CSN 24 EPAD 25

GND
GND¹⁰⁵ C⁶ ¹⁰K R¹

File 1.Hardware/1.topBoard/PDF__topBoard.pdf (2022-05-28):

排针接口 | 安装时需要去掉塑料部分

# 三向开关

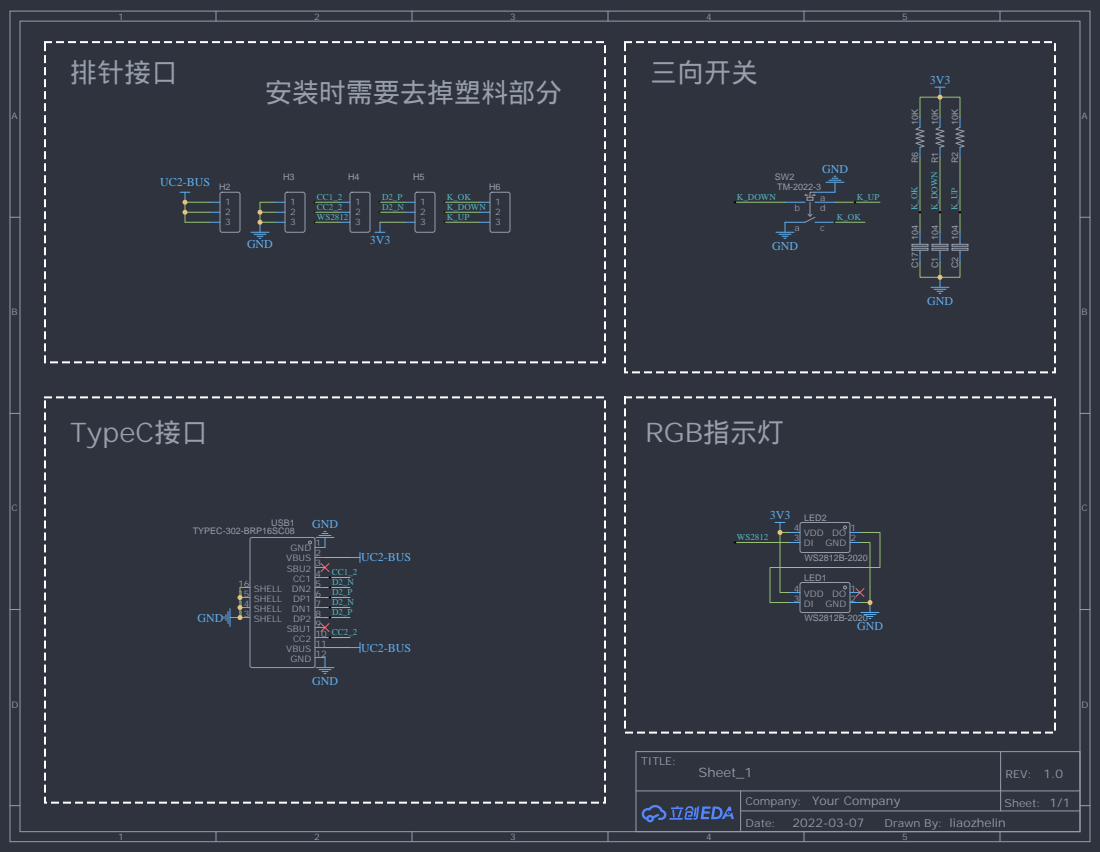
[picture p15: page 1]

SHELL 13 SHELL 14 SHELL 15 SHELL 16

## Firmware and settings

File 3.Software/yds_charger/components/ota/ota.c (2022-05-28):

/* Advanced HTTPS OTA example

   This example code is in the Public Domain (or CC0 licensed, at your option.)

   Unless required by applicable law or agreed to in writing, this
   software is distributed on an "AS IS" BASIS, WITHOUT WARRANTIES OR
   CONDITIONS OF ANY KIND, either express or implied.
*/
#include <string.h>
#include "freertos/FreeRTOS.h"
#include "freertos/task.h"
#include "freertos/event_groups.h"
#include "esp_system.h"
#include "esp_event.h"
#include "esp_log.h"
#include "esp_ota_ops.h"
#include "esp_http_client.h"
#include "esp_https_ota.h"
#include "nvs.h"
#include "nvs_flash.h"
#include "protocol_examples_common.h"
#include <driver/gpio.h>

#if CONFIG_BOOTLOADER_APP_ANTI_ROLLBACK
#include "esp_efuse.h"
#endif

#if CONFIG_EXAMPLE_CONNECT_WIFI
#include "esp_wifi.h"
#endif

#if CONFIG_BT_BLE_ENABLED || CONFIG_BT_NIMBLE_ENABLED
#include "ble_api.h"
#endif

static const char *TAG = "advanced_https_ota_example";
extern const uint8_t server_cert_pem_start[] asm("_binary_ca_cert_pem_start");
extern const uint8_t server_cert_pem_end[] asm("_binary_ca_cert_pem_end");

#define OTA_URL_SIZE 256

static esp_err_t validate_image_header(esp_app_desc_t *new_app_info)
{
    if (new_app_info == NULL) {
        return ESP_ERR_INVALID_ARG;
    }

    const esp_partition_t *running = esp_ota_get_running_partition(); //获取当前运行的应用程序的分区信息
    esp_app_desc_t running_app_info;
    if (esp_ota_get_partition_description(running, &running_app_info) == ESP_OK) { //返回正在运行引用程序分区的版本号
        ESP_LOGI(TAG, "Running firmware version: %s", running_app_info.version);  //打印版本号
    }

#ifndef CONFIG_EXAMPLE_SKIP_VERSION_CHECK
    if (memcmp(new_app_info->version, running_app_info.version, sizeof(new_app_info->version)) == 0) { //比较版本号，如果一样则退出
        ESP_LOGW(TAG, "Current running version is the same as a new. We will not continue the update.");
        return ESP_FAIL;
    }
#endif

#ifdef CONFIG_BOOTLOADER_APP_ANTI_ROLLBACK
    /**
     * Secure version check from firmware image header prevents subsequent download and flash write of
     * entire firmware image. However this is optional because it is also taken care in API
     * esp_https_ota_finish at the end of OTA update procedure.
     */
    const uint32_t hw_sec_version = esp_efuse_read_secure_version();//从efuse字段返回secure_version
    if (new_app_info->secure_version < hw_sec_version) { //判断硬件版本号，如果比当前版本更低则不升级
        ESP_LOGW(TAG, "New firmware security version is less than eFuse programmed, %d < %d", new_app_info->secure_version, hw_sec_version);
        return ESP_FAIL;
    }
#endif

    return ESP_OK; //都满足，返回success
}

static esp_err_t _http_client_init_cb(esp_http_client_handle_t http_client)
{
    esp_err_t err = ESP_OK;
    /* Uncomment to add custom headers to HTTP request */
    // err = esp_http_client_set_header(http_client, "Custom-Header", "Value");
    return err;
}

void advanced_ota_example_task(void *pvParameter)
{
    ESP_LOGI(TAG, "Starting Advanced OTA example");

    esp_err_t ota_finish_err = ESP_OK;
    esp_http_client_config_t config = {
        .url = CONFIG_EXAMPLE_FIRMWARE_UPGRADE_URL, //服务URL
        .cert_pem = (char *)server_cert_pem_start, //SSL证书
        .timeout_ms = CONFIG_EXAMPLE_OTA_RECV_TIMEOUT,
        .keep_alive_enable = true,
    };

#ifdef CONFIG_EXAMPLE_FIRMWARE_UPGRADE_URL_FROM_STDIN  //从文件系统中读取URL
    char url_buf[OTA_URL_SIZE];
    if (strcmp(config.url, "FROM_STDIN") == 0) {
        example_configure_stdin_stdout();
        fgets(url_buf, OTA_URL_SIZE, stdin);
        int len = strlen(url_buf);
        url_buf[len - 1] = '\0';
        config.url = url_buf;
    } else {
        ESP_LOGE(TAG, "Configuration mismatch: wrong firmware upgrade image url");
        abort();
    }
#endif

#ifdef CONFIG_EXAMPLE_SKIP_COMMON_NAME_CHECK
    config.skip_cert_common_name_check = true;
#endif

    esp_https_ota_config_t ota_config = {
        .http_config = &config,
        .http_client_init_cb = _http_client_init_cb, // Register a callback to be invoked after esp_http_client is initialized
#ifdef CONFIG_EXAMPLE_ENABLE_PARTIAL_HTTP_DOWNLOAD
        .partial_http_download = true,
        .max_http_request_size = CONFIG_EXAMPLE_HTTP_REQUEST_SIZE,
#endif
    };

    esp_https_ota_handle_t https_ota_handle = NULL;
    esp_err_t err = esp_https_ota_begin(&ota_config, &https_ota_handle); //调用begin，开始ota，检查http地址有效性，返回https_ota_handle
    if (err != ESP_OK) {
        ESP_LOGE(TAG, "ESP HTTPS OTA Begin failed");
        vTaskDelete(NULL);
    }

    esp_app_desc_t app_desc;
    err = esp_https_ota_get_img_desc(https_ota_handle, &app_desc);//从镜像描述中，读取固件版本等信息信息
    if (err != ESP_OK) {
        ESP_LOGE(TAG, "esp_https_ota_read_img_desc failed");
        goto ota_end;
    }
    err = validate_image_header(&app_desc);//校验镜像头，判断是否需要更新
    if (err != ESP_OK) {
        ESP_LOGE(TAG, "image header verification failed");
        goto ota_end;
    }

    while (1) {
        err = esp_https_ota_perform(https_ota_handle); //从HTTP流中读取图像数据并将其写入OTA分区
        if (err != ESP_ERR_HTTPS_OTA_IN_PROGRESS) {
            break;
        }
        // esp_https_ota_perform returns after every read operation which gives user the ability to
        // monitor the status of OTA upgrade by calling esp_https_ota_get_image_len_read, which gives length of image
        // data read so far.
        ESP_LOGD(TAG, "Image bytes read: %d", esp_https_ota_get_image_len_read(https_ota_handle));
    }

    if (esp_https_ota_is_complete_data_received(https_ota_handle) != true) {  //检测是否接收到完整数据
        // the OTA image was not completely received and user can customise the response to this situation.
        ESP_LOGE(TAG, "Complete data was not received.");  //没有升级成功
    } else {
        ota_finish_err = esp_https_ota_finish(https_ota_handle);  //清理HTTPS OTA固件升级和关闭HTTPS连接，并切换启动分区到新镜像OTA分区
        if ((err == ESP_OK) && (ota_finish_err == ESP_OK)) {
            ESP_LOGI(TAG, "ESP_HTTPS_OTA upgrade successful. Rebooting ...");
            vTaskDelay(1000 / portTICK_PERIOD_MS);
            esp_restart(); //当esp_https_ota_finish后，调用此从新镜像启动
        } else {
            if (ota_finish_err == ESP_ERR_OTA_VALIDATE_FAILED) {
                ESP_LOGE(TAG, "Image validation failed, image is corrupted");
            }
            ESP_LOGE(TAG, "ESP_HTTPS_OTA upgrade failed 0x%x", ota_finish_err);
            vTaskDelete(NULL);
        }
    }

ota_end:
    esp_https_ota_abort(https_ota_handle);//清理HTTPS OTA固件升级和关闭HTTPS连接，停止OTA更新
    ESP_LOGE(TAG, "ESP_HTTPS_OTA upgrade failed");
    vTaskDelete(NULL);//删除OTA任务
}

void OTA_Init(void){
    ESP_ERROR_CHECK(esp_netif_init()); //初始化底层的TCP/IP协议栈
    ESP_ERROR_CHECK(esp_event_loop_create_default()); //创建默认的事件循环
    
    ESP_ERROR_CHECK(example_connect());//连接Wifi

    esp_wifi_set_ps(WIFI_PS_NONE); //设置wifi为不省电模式
}
// void app_main(void)
// {
//     // Initialize NVS.
//     esp_err_t err = nvs_flash_init();
//     if (err == ESP_ERR_NVS_NO_FREE_PAGES || err == ESP_ERR_NVS_NEW_VERSION_FOUND) {
//         // 1.OTA app partition table has a smaller NVS partition size than the non-OTA
//         // partition table. This size mismatch may cause NVS initialization to fail.
//         // 2.NVS partition contains data in new format and cannot be recognized by this version of code.
//         // If this happens, we erase NVS partition and initialize NVS again.
//         ESP_ERROR_CHECK(nvs_flash_erase());
//         err = nvs_flash_init();
//     }
//     ESP_ERROR_CHECK( err );

//     ESP_ERROR_CHECK(esp_netif_init()); //初始化底层的TCP/IP协议栈
//     ESP_ERROR_CHECK(esp_event_loop_create_default()); //创建默认的事件循环

//     /* This helper function configures Wi-Fi or Ethernet, as selected in menuconfig.
//      * Read "Establishing Wi-Fi or Ethernet Connection" section in
//      * examples/protocols/README.md for more information about this function.
//     */
//     ESP_ERROR_CHECK(example_connect());//连接Wifi

// #if defined(CONFIG_BOOTLOADER_APP_ROLLBACK_ENABLE)
//     /**
//      * We are treating successful WiFi connection as a checkpoint to cancel rollback  将成功Wifi连接作为一个检查点
//      * process and mark newly updated firmware image as active. For production cases,
//      * please tune the checkpoint behavior per end application requirement.
//      */
//     const esp_partition_t *running = esp_ota_get_running_partition();//获取当前运行版本号
//     esp_ota_img_states_t ota_state;
//     if (esp_ota_get_state_partition(running, &ota_state) == ESP_OK) { //返回运行分区的状态
//         if (ota_state == ESP_OTA_IMG_PENDING_VERIFY) { //第一次从此分区启动
//             if (esp_ota_mark_app_valid_cancel_rollback() == ESP_OK) { //判断当前运行的APP状态是否工作正常
//                 ESP_LOGI(TAG, "App is valid, rollback cancelled successfully");
//             } else {
//                 ESP_LOGE(TAG, "Failed to cancel rollback");
//             }
//         }
//     }
// #endif

// #if CONFIG_EXAMPLE_CONNECT_WIFI
// #if !CONFIG_BT_ENABLED
//     /* Ensure to disable any WiFi power save mode, this allows best throughput
//      * and hence timings for overall OTA operation.
//      */
//     esp_wifi_set_ps(WIFI_PS_NONE); //设置wifi为不省电模式
// #else //有蓝牙的状态
//     /* WIFI_PS_MIN_MODEM is the default mode for WiFi Power saving. When both
//      * WiFi and Bluetooth are running, WiFI modem has to go down, hence we
//      * need WIFI_PS_MIN_MODEM. And as WiFi modem goes down, OTA download time
//      * increases.
//      */
//     esp_wifi_set_ps(WIFI_PS_MIN_MODEM);
// #endif // CONFIG_BT_ENABLED
// #endif // CONFIG_EXAMPLE_CONNECT_WIFI

// #if CONFIG_BT_BLE_ENABLED || CONFIG_BT_NIMBLE_ENABLED
//     esp_ble_helper_init(); //通过蓝牙OTA??
// #endif

//     xTaskCreate(&advanced_ota_example_task, "advanced_ota_example_task", 1024 * 8, NULL, 5, NULL);
//     gpio_pad_select_gpio(3);
//     gpio_set_direction(3, GPIO_MODE_OUTPUT);
//     for(;;){
//         gpio_set_level(3, 1);
//         vTaskDelay(pdMS_TO_TICKS(200));
//         gpio_set_level(3, 0);
//         vTaskDelay(pdMS_TO_TICKS(200));
//     }
// }

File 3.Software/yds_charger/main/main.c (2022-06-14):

/*
 * @Author: [LiaoZhelin]
 * @Date: 2022-04-03 10:05:08
 * @LastEditors: [LiaoZhelin]
 * @LastEditTime: 2022-06-14 13:26:23
 * @Description:
 */
// System:
#include <stdio.h>
#include <string.h>
#include "freertos/FreeRTOS.h"
#include "freertos/task.h"
#include "freertos/event_groups.h"
#include "esp_system.h"
#include "esp_log.h"
#include "lwip/err.h"
#include "lwip/sys.h"
#include "nvs_flash.h"
#include "sdkconfig.h"
#include "esp_event.h"

// User:
#include "wifi.h"
#include "adc_read.h"
#include "lis3dh.h"
#include "led_strip.h"
#include "sw3526.h"
#include "led_strip.h"
#include "driver/rmt.h"
#include <driver/gpio.h>
#include "menu.h"
#include "u8g2_esp32_hal.h"
#include "ota.h"
#include "sntptime.h"

#include "task.h"

static const char *TAG = "main";

#define RMT_TX_CHANNEL RMT_CHANNEL_0


void GPIO_Init(void){
  //Input GPIO
  gpio_pad_select_gpio(8);
  gpio_set_direction(8, GPIO_MODE_INPUT);
  gpio_set_pull_mode(8,GPIO_PULLUP_ONLY);
  gpio_pad_select_gpio(9);
  gpio_set_direction(9, GPIO_MODE_INPUT);
  gpio_set_pull_mode(9,GPIO_PULLUP_ONLY);
  gpio_pad_select_gpio(10);
  gpio_set_direction(10, GPIO_MODE_INPUT);
  gpio_set_pull_mode(10,GPIO_PULLUP_ONLY);

  //Output GPIO
  gpio_pad_select_gpio(20);
  gpio_set_direction(20, GPIO_MODE_OUTPUT);
  gpio_set_level(20, 1);
  
  //Output GPIO
  gpio_pad_select_gpio(21);
  gpio_set_direction(21, GPIO_MODE_OUTPUT);
  gpio_set_level(21, 1);
}

void NVS_Init(void){
  esp_err_t ret;
  ret = nvs_flash_init();
  if (ret == ESP_ERR_NVS_NO_FREE_PAGES || ret == ESP_ERR_NVS_NEW_VERSION_FOUND)
  {
    ESP_ERROR_CHECK(nvs_flash_erase());
    ret = nvs_flash_init();
  }
  ESP_ERROR_CHECK(ret);
}

void ALL_Init(void){
  //Initization
  nvs_handle_t wificonfig_handle;
  uint8_t s_WifiConfigVal;

  u8g2_Init();// Init I2C
  oledInitMessageTask(1,"");
  NVS_Init();
  ADC_Init();
  strip = led_strip_init(RMT_CHANNEL_0, GPIO_NUM_4, 4);
  GPIO_Init();
  oledInitMessageTask(1,"OK");
  vTaskDelay(pdMS_TO_TICKS(200));
  oledInitMessageTask(2,"");
  SW35xxInit();
  oledInitMessageTask(2,"OK");
  vTaskDelay(pdMS_TO_TICKS(200));
  oledInitMessageTask(3,"");
  LIS3DH_Init();// No init I2C
  oledInitMessageTask(3,"OK");
  vTaskDelay(pdMS_TO_TICKS(200));

  oledInitMessageTask(4,"");
  ESP_ERROR_CHECK(nvs_open("WifiConfigFlag",NVS_READWRITE,&wificonfig_handle));
  nvs_get_u8(wificonfig_handle,"WifiConfigFlag",&s_WifiConfigVal);

  if(s_WifiConfigVal == wifi_configed){
    if(wifi_init_sta(0)){
      oledInitMessageTask(4,"OK");
      vTaskDelay(pdMS_TO_TICKS(200));
      SNTP_Init();
    }
    else{
      oledInitMessageTask(4,"ER");
      vTaskDelay(pdMS_TO_TICKS(2000));
    }
  }
  else{
    oledInitMessageTask(4,"NO");
    ESP_LOGI(TAG,"No Config Wifi");
    vTaskDelay(pdMS_TO_TICKS(200));
    
    nvs_close(wificonfig_handle);
  }
  //OTA_Init(); // Init Wifi
  
  //TaskCreate
  xTaskCreate(adcTask, "adcTask", 1024, NULL, 1, &adcTask_handle);
  xTaskCreate(sw35xxTask, "sw35xxTask", 1024, NULL, 1, &sw35xxTask_handle);
  xTaskCreate(lis3dhTask, "lis3dhtask", 1024, NULL, 1, &lis3dhtask_handle);
  xTaskCreate(oledTask, "oledtask", 1024 * 3, NULL, 1, &oledTask_handle);
  xTaskCreate(ws28xxTask, "ws28xxTask", 1024, NULL, 0, &ws28xxTask_handle); 
  xTaskCreate(ntpClockTask, "ntpClockTask", 1024, NULL, 0, &ntpTask_handle);
  //DEBUG STACK SIZE
  xTaskCreate(taskMonitor,"taskMonitor",1024*2,NULL,1,NULL); 
}

void app_main(void)
{
  ALL_Init();
  for (;;)
  {
    vTaskDelay(pdMS_TO_TICKS(1000));
    ota_process
  }
}

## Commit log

2022-05-27 第一次Commit
2022-05-28 增加3D结构文件，手册文件等
    [3D_2_PCB_Daughter-Board_2022-04-09_2022-04-09.step, OLED TFT 0.96 inch 64x128 monochrome.SLDPRT, OLED TFT 0.96 inch 64x128 monochrome.STEP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]
2022-05-28 更新MD文件
2022-05-28 修改README
2022-05-28 增加坐标文件，BOM表，规范文件命名格式
    [BOM__topBoard.csv, BOM_bottomBoard.csv, PickAndPlace__topBoard.csv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]
2022-05-28 增加项目源码工程
    [3D_2_PCB_Daughter-Board_2022-04-09_2022-04-09.step, OLED TFT 0.96 inch 64x128 monochrome.SLDPRT, OLED TFT 0.96 inch 64x128 monochrome.STEP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]
2022-05-28 修改README文件
2022-05-29 更新README
2022-05-29 增加上层版易打样版本（FIX）
2022-05-30 增加动态BOM，说明文件
2022-05-30 [1]增加器件采购指南 [2]修正下层板动态BOM [3]修改README
2022-06-01 [1]提交不同丝印版本的文件
2022-06-06 修改了原理图以及BOM中一些器件的选型标注问题
    [BOM_bottomBoard.csv]
2022-06-11 提交BOM完善
    [BOM_bottomBoard.csv]
2022-06-13 [1]修改工程中的依赖错误 [2]修改固件，增加合并固件 [3]修改README
2022-06-13 修正客户Wifi的nvs逻辑
2022-06-13 修改合并固件
2022-06-13 修复Wifi初次nvs故障
2022-06-14 优化STACK使用，增加NTP任务，待实现
2022-06-14 验证完NTP服务功能
2022-06-14 暂存menu修改
2022-07-12 [1]修正3904发热问题 [2]将动态BOM关联网络以及铜皮走线
    [BOM_bottomBoard.csv]
